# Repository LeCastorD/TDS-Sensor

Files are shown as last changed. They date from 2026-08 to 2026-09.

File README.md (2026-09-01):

<div align="center">
  <h1>TDS Sensor</h1>
  <p><strong>ESP8266 TDS and temperature sensor for Home Assistant</strong></p>
  <p>
    <a href="#build-with-platformio">Build</a> |
    <a href="#wiring">Wiring</a> |
    <a href="#enclosure-and-assembly">Enclosure</a> |
    <a href="#first-setup">First setup</a>
  </p>
</div>

<p align="center">
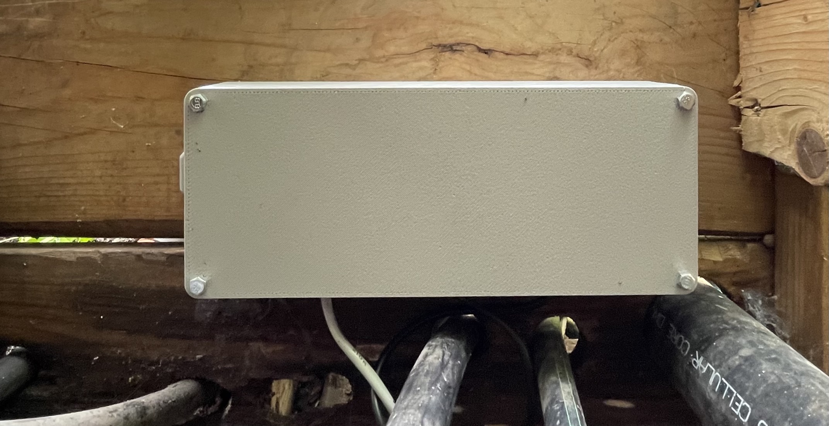
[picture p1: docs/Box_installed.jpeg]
Installed TDS Sensor enclosure
  
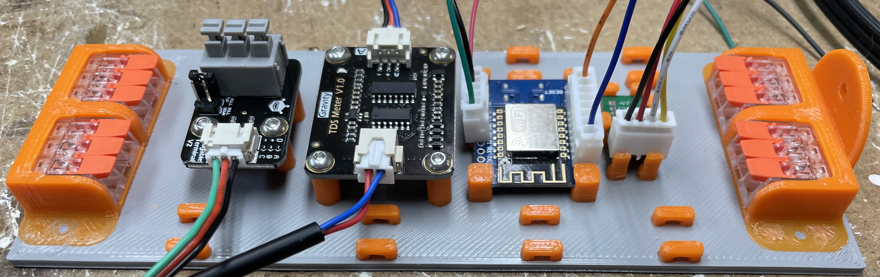
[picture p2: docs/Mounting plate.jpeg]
Populated sensor mounting plate
  
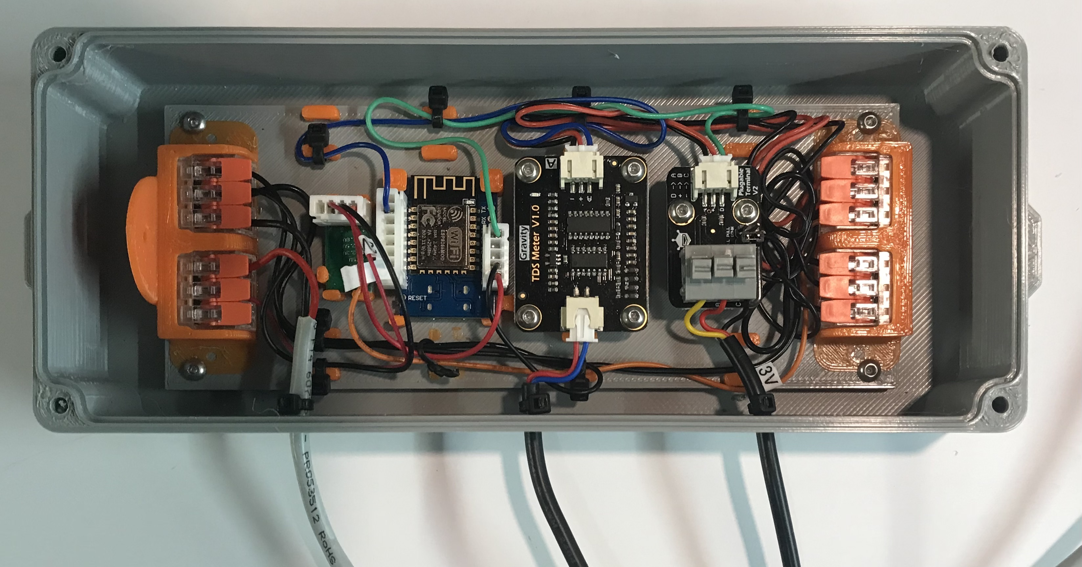
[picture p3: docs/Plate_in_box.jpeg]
Mounting plate installed in the enclosure
  
</p>

<h2 id="table-of-contents">Table of Contents</h2>

<ul>
  <li><a href="#overview">Overview</a></li>
  <li><a href="#features">Features</a></li>
  <li><a href="#hardware">Hardware</a></li>
  <li><a href="#device-naming">Device naming</a></li>
  <li><a href="#component-reference">Component reference</a></li>
  <li><a href="#soldering">Soldering the power and controller connections</a></li>
  <li><a href="#buck-converter-5v-jumper">Buck converter 5 V jumper</a></li>
  <li><a href="#crimping-and-wire-preparation">Crimping connectors and preparing wires</a></li>
  <li><a href="#wiring">Wiring</a></li>
  <li><a href="#bill-of-materials">Bill of materials</a></li>
  <li><a href="#enclosure-and-assembly">Enclosure and assembly</a></li>
  <li><a href="#build-with-platformio">Build with PlatformIO</a></li>
  <li><a href="#upload-firmware">Upload firmware</a></li>
  <li><a href="#ota-upgrade">OTA upgrade and LittleFS data</a></li>
  <li><a href="#initial-wi-fi-configuration">Initial Wi-Fi configuration</a></li>
  <li><a href="#default-web-ui-login">Default Web UI login</a></li>
  <li><a href="#first-setup">First setup</a></li>
  <li><a href="#web-ui-reference">Web UI reference</a></li>
  <li><a href="#home-assistant-interface">Home Assistant interface</a></li>
  <li><a href="#security">Security</a></li>
  <li><a href="#repository-layout">Repository layout</a></li>
  <li><a href="#license">License</a></li>
  <li><a href="#disclaimer">Disclaimer</a></li>
</ul>

<h2 id="overview">Overview</h2>

<p>
  This project measures total dissolved solids (TDS) and water temperature with an ESP8266 controller. It reads a DFRobot SEN0244 analog TDS sensor, applies temperature compensation using a DS18B20 probe, and publishes readings through MQTT for Home Assistant.
</p>

<p>
  <strong>TDS range limitation:</strong> the DFRobot SEN0244 has a specified measurement range of <strong>0 to 1000 ppm</strong>. A calculated value above 1000 ppm is outside the sensor's validated recognition range and should not be treated as an accurate measurement; the sensor cannot reliably distinguish higher concentrations. The firmware may still display values above 1000 ppm because its analog calculation is not hard-clamped, but changing the calibration factor does not extend the physical sensor range. See the <a href="https://wiki.dfrobot.com/sen0244/">DFRobot SEN0244 specifications</a> for the manufacturer's range and accuracy information.
</p>

<p>
  <strong>Wi-Fi limitations:</strong> the Wemos D1 Mini used by this project is based on the ESP8266 and supports 2.4 GHz 802.11 b/g/n Wi-Fi, not 5 GHz Wi-Fi. For reliable onboarding and operation, use a dedicated 2.4 GHz network configured for b/g/n compatibility rather than a 5 GHz-only or 802.11ac-only network. Modern access points can sometimes handle this through backward-compatible mixed modes, but a separate legacy-compatible SSID is recommended when the device has connection problems.
</p>

<p>
  The standard Wemos board is best placed within good Wi-Fi coverage. If there is no nearby repeater or access point, consider a compatible ESP8266 board with an external antenna connector, such as an IPEX/U.FL or SMA connector, and a suitable antenna. An external antenna can improve placement flexibility and coverage, but actual performance depends on the antenna, cable, enclosure, and access point. Verify pin compatibility and physical fit before substituting the controller; see the <a href="https://docs.wemos.cc/en/latest/d1/d1_mini.html">WEMOS D1 mini documentation</a>, the <a href="https://docs.wemos.cc/en/latest/d1/d1_mini_pro.html">WEMOS D1 mini Pro documentation</a>, and the <a href="https://documentation.espressif.com/0a-esp8266ex_datasheet_en.html">Espressif ESP8266EX datasheet</a> for board and radio details.
</p>

<h2 id="features">Features</h2>

<ul>
  <li>TDS measurement in ppm through an analog input</li>
  <li>DS18B20 temperature measurement and temperature compensation</li>
  <li>WiFiManager onboarding</li>
  <li>MQTT state publishing and Home Assistant MQTT discovery</li>
  <li>Browser-based configuration and sensor calibration</li>
  <li>OTA firmware updates</li>
  <li>LittleFS configuration and sensor log storage</li>
  <li>Factory reset input on the controller board</li>
</ul>

<h2 id="hardware">Hardware</h2>

<ul>
  <li>Wemos D1 Mini (ESP8266)</li>
  <li>DFRobot SEN0244 analog TDS sensor</li>
  <li>DFRobot DS18B20 temperature probe</li>
  <li>5 V supply for the controller board</li>
  <li>Optional 12 V supply and 12-24 V to 5 V buck converter</li>
</ul>

<h2 id="device-naming">Device naming</h2>

<p>
  When no custom name is saved, the firmware generates the device name using this format:
  <code>tds-tmp-sensor-XXXXXX</code>
</p>

<ul>
  <li>Prefix: <code>tds-tmp-sensor-</code></li>
  <li>Suffix: six uppercase hexadecimal characters</li>
  <li>Identifier source: the ESP8266 value returned by <code>ESP.getChipId()</code>, masked to 24 bits</li>
</ul>

<p>Example: <code>tds-tmp-sensor-ABC123</code>.</p>

<p>
  The code does not take the last four characters of the Wi-Fi MAC address. The helper function is named <code>applyDefaultIdentityFromMac()</code>, but its current implementation uses <code>ESP.getChipId()</code> to create a six-character suffix.
</p>

<p>
  A custom name can be saved from the network settings page. When set, that name replaces the generated default and is used as the Wi-Fi hostname, the mDNS hostname (<code>http://&lt;device-name&gt;.local</code>), the WiFiManager portal name, and the Home Assistant MQTT discovery device identifier.
</p>

<h2 id="component-reference">Component reference</h2>

<p>The following reference photos identify the main electronic, wiring, power, and assembly tools used by this project.</p>

<table>
  <tr>
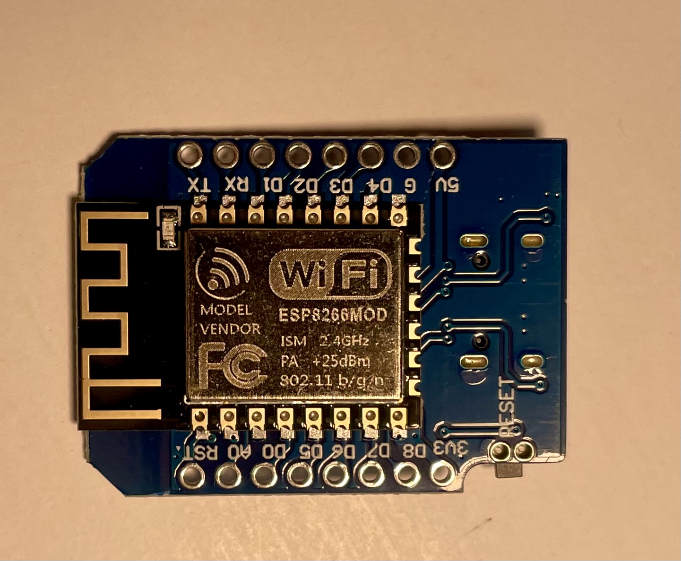
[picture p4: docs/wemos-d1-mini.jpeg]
Wemos D1 Mini ESP8266 board
    <td align="center"><br><em>Wemos D1 Mini</em></td>
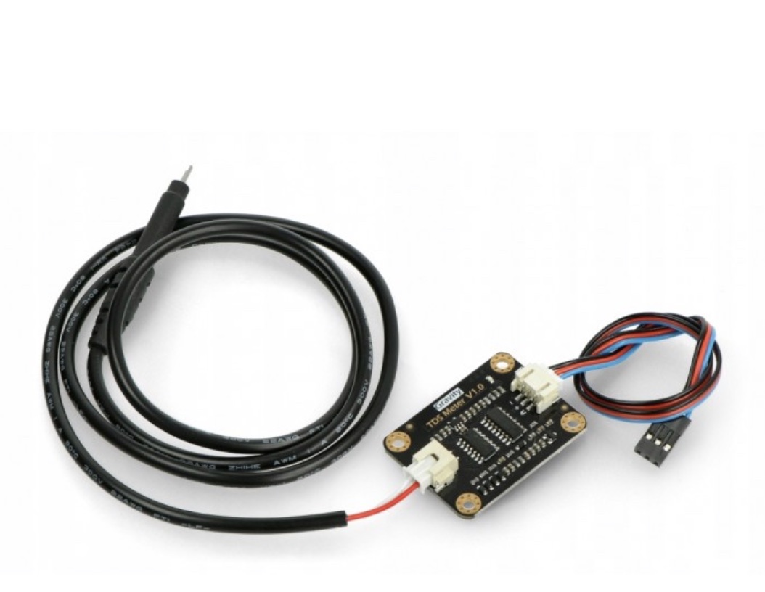
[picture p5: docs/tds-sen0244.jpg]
DFRobot SEN0244 TDS sensor
    <td align="center"><br><em>DFRobot SEN0244 TDS sensor</em></td>
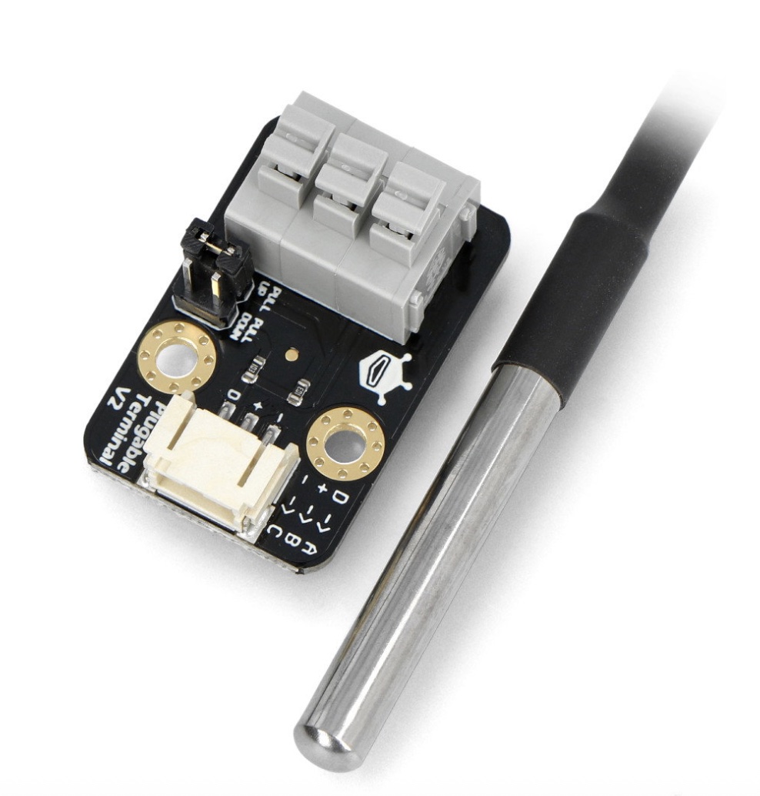
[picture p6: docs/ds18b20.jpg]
DFRobot DS18B20 temperature sensor
    <td align="center"><br><em>DFRobot DS18B20</em></td>
  </tr>
  <tr>
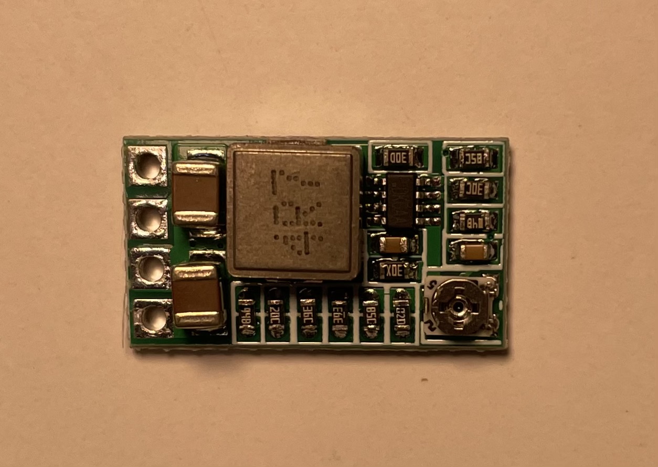
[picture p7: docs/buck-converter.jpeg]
12 to 5 volt buck converter
    <td align="center"><br><em>12-24 V to 5 V buck converter</em></td>
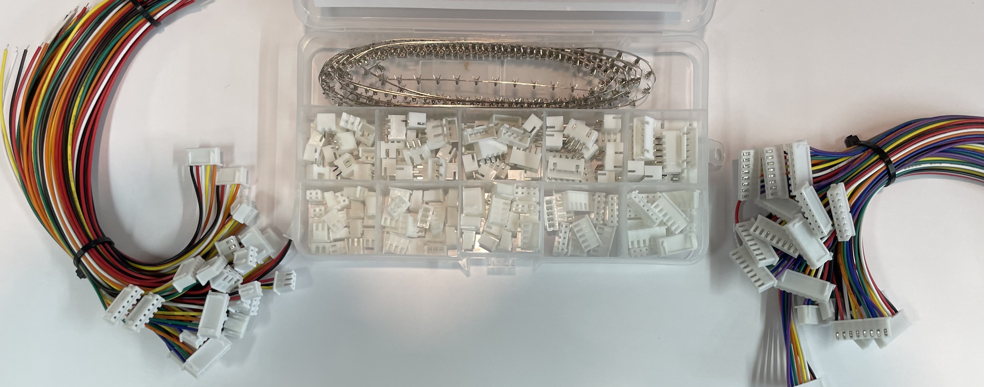
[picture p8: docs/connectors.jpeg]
JST XH connector kit
    <td align="center"><br><em>JST-XH connector kit</em></td>
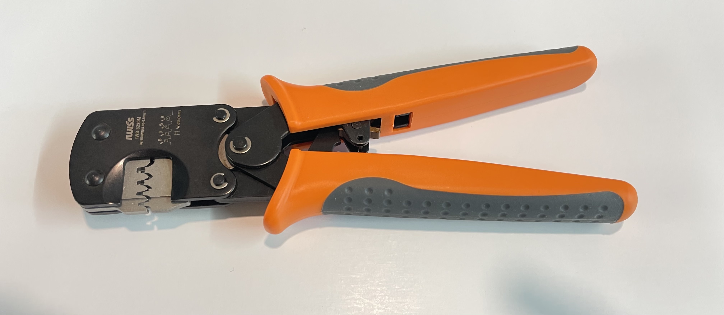
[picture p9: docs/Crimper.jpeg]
JST connector crimping tool
    <td align="center"><br><em>JST connector crimping tool</em></td>
  </tr>
</table>

<h2 id="soldering">Soldering the power and controller connections</h2>

<p>
  Disconnect the 12 V supply and USB cable before soldering. Work from the labels printed on each board and verify every connection with a multimeter before applying power.
</p>

<table>
  <tr>
    <td align="center">Buck converter for the controller power supply<br><em>Buck converter</em></td>
    <td align="center">Wemos D1 Mini controller board<br><em>Wemos D1 Mini</em></td>
  </tr>
</table>

<ol>
  <li>Identify the buck-converter input and output pads. Connect the 12 V supply to <code>IN+</code> and <code>IN-</code>, observing polarity.</li>
  <li>Connect the regulated output to the controller power wiring: <code>OUT+</code> to the Wemos <code>5V</code> pin and <code>OUT-</code> to <code>GND</code>.</li>
  <li>Before connecting the Wemos, power the buck converter from the supply and adjust or verify its output at approximately 5.0 V DC.</li>
  <li>Solder short, clearly identified leads or connector wires to the Wemos pins required by the installation: <code>5V</code>, <code>3V3</code>, <code>GND</code>, <code>A0</code>, <code>D2</code> / <code>GPIO4</code>, and the optional <code>D5</code> / <code>GPIO14</code> factory-reset input. The <code>3V3</code> connection powers the SEN0244 and DS18B20.</li>
  <li>Use heat-shrink tubing on exposed solder joints and add strain relief so the connector cannot pull directly on a pad.</li>
  <li>Check continuity, polarity, and the absence of shorts between <code>5V</code> and <code>GND</code> before connecting the Wemos and sensors.</li>
</ol>

<p><strong>Important:</strong> never connect the 12 V supply directly to the Wemos <code>5V</code> pin, and never connect the buck converter's 5 V output directly to a sensor power input. The buck converter feeds only the Wemos <code>5V</code> pin; the Wemos supplies the SEN0244 and DS18B20 from its <code>3V3</code> and <code>GND</code> pins.</p>

<h3 id="buck-converter-5v-jumper">Set the buck converter to 5 V</h3>

<p>
  This buck-converter board uses solder-selectable output pads on its back. The Wemos requires a regulated 5 V input, while the SEN0244 and DS18B20 are powered from the Wemos <code>3V3</code> rail. Bridge only the two pads marked <code>5V</code> before connecting the controller.
</p>

<p align="center">
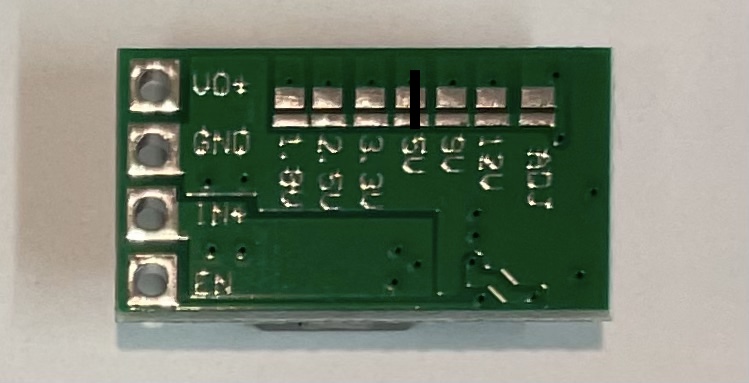
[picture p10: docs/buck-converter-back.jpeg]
Back of the buck converter showing the solder-selectable voltage pads
  
</p>

<ol>
  <li>Disconnect the 12 V supply and USB cable from the project.</li>
  <li>Turn the converter over and locate the output-selection row and the <code>5V</code> marking shown in the reference image.</li>
  <li>Use a small amount of flux and solder to bridge the two pads for the <code>5V</code> selection.</li>
  <li>Check that the solder bridge does not touch the neighboring voltage-selection pads. Remove any unintended bridge before powering the board.</li>
  <li>Power the converter from the 12 V supply and measure between <code>VOUT+</code> and <code>GND</code>. Confirm approximately 5.0 V DC before connecting the Wemos.</li>
</ol>

<p><strong>Important:</strong> the jumper selects the converter output voltage; it does not replace the voltage measurement. Do not connect the Wemos until the measured output is correct.</p>

<h2 id="crimping-and-wire-preparation">Crimping connectors and preparing wires</h2>

<p>
  This section refers to the JST-XH/XH2.54 connectors listed in the BOM. Use the correct contact size and housing for the prewired connector kit; do not force a terminal into a mismatched housing.
</p>

<p align="center">
  JST-XH connector kit and prewired wires
  JST connector crimping tool
</p>

<ol>
  <li>Install the buck converter, Wemos, terminal blocks, and sensor electronics in their final positions on the mounting plate before measuring wires.</li>
  <li>Route each wire along its final path and measure from connector to connector. Keep runs as short as practical, but leave enough slack to unplug a connector and remove the plate without stressing the wires.</li>
  <li>Cut and label one wire at a time. Keep power, ground, analog signal, and one-wire data conductors identifiable at both ends.</li>
  <li>Plan the sensor power branches from the Wemos: route <code>3V3</code> to the SEN0244 supply and the DS18B20 power lead, and route <code>GND</code> back to the Wemos common ground. Do not route the buck converter's <code>5V</code> output to either sensor.</li>
  <li>Strip only the length required by the contact manufacturer, typically about 2-3 mm for small JST-XH contacts. Do not nick or remove conductor strands.</li>
  <li>Place the stripped conductor in the contact so the conductor wings crimp onto bare copper and the insulation wings support the cable jacket.</li>
  <li>Crimp with the correct die position, then inspect the joint. The conductor should be held firmly without cutting through the wire or leaving loose strands.</li>
  <li>Perform a gentle pull test on every crimp, then insert the contact into the housing until the locking tang clicks. Confirm the pin order and connector keying before mating it.</li>
  <li>Use a multimeter to verify continuity end-to-end and confirm that adjacent pins are not shorted.</li>
</ol>

<table>
  <thead>
    <tr>
      <th>Connection</th>
      <th>Routing guidance</th>
    </tr>
  </thead>
  <tbody>
    <tr>
      <td>Buck <code>OUT+</code> to Wemos <code>5V</code></td>
      <td>Use the shortest safe power run and verify 5 V before connection.</td>
    </tr>
    <tr>
      <td>Buck <code>OUT-</code> to Wemos <code>GND</code></td>
      <td>Use a short ground run; the Wemos <code>GND</code> is the common return for both sensors.</td>
    </tr>
    <tr>
      <td>Wemos <code>3V3</code> to SEN0244 and DS18B20 power</td>
      <td>Branch the Wemos 3.3 V rail to both sensor supply inputs. Never use buck <code>OUT+</code> for sensor power.</td>
    </tr>
    <tr>
      <td>Wemos <code>GND</code> to SEN0244 and DS18B20 ground</td>
      <td>Keep the sensor returns common with the Wemos and buck-converter ground.</td>
    </tr>
    <tr>
      <td>Wemos <code>A0</code> to SEN0244 analog output</td>
      <td>Keep the analog signal wire short and separated from unnecessary power loops.</td>
    </tr>
    <tr>
      <td>Wemos <code>D2</code> / <code>GPIO4</code> to DS18B20 data</td>
      <td>Route directly to the temperature connector and avoid excess coiled wire.</td>
    </tr>
  </tbody>
</table>

<p>
  The goal is a compact harness with no loose loops, while retaining enough service slack for inspection, connector removal, and enclosure maintenance. See <a href="docs/BOM.md#component-images">docs/BOM.md</a> for the component images and parts list.
</p>

<h2 id="wiring">Wiring</h2>

<p align="center">
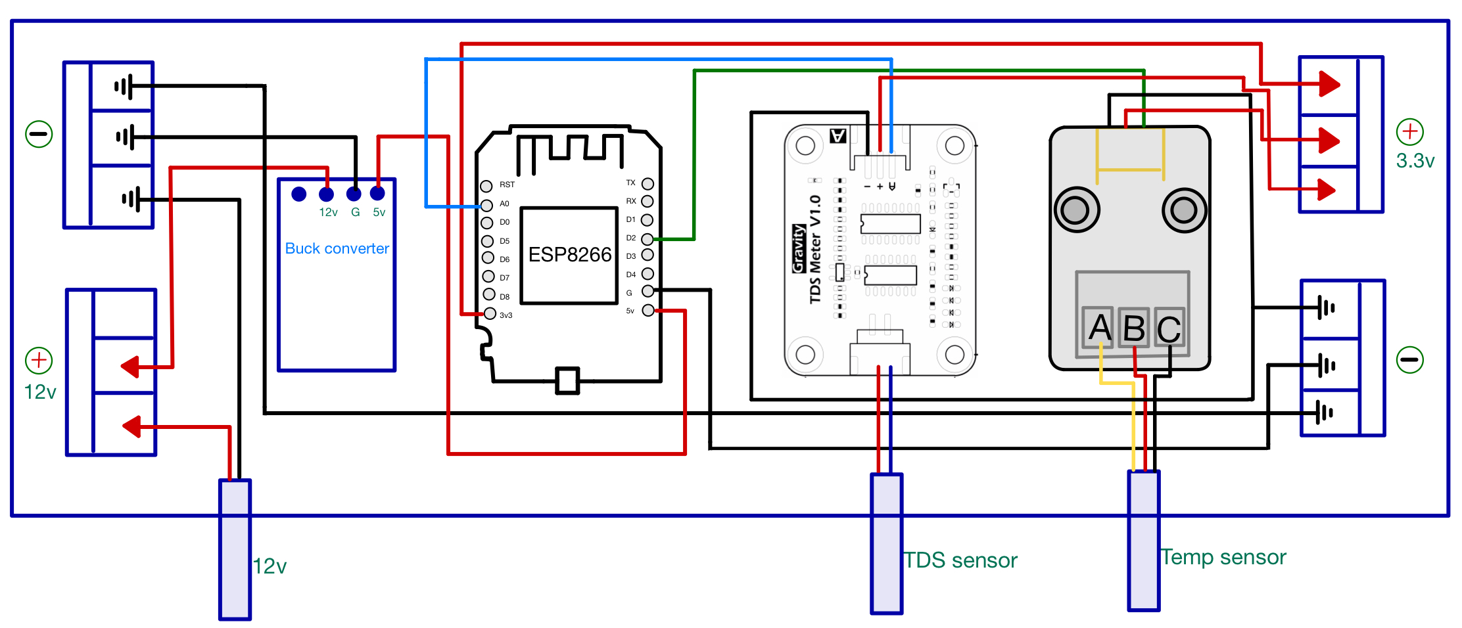
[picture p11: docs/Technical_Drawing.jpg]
TDSTMPSensor technical wiring drawing showing the buck converter, Wemos, TDS sensor, and temperature sensor connections
  <br>
  <em>Technical wiring drawing: 12 V supply to the buck converter, buck converter 5 V output to the Wemos, and Wemos 3.3 V power to both sensors.</em>
</p>

<table>
  <thead>
    <tr>
      <th>Controller pin</th>
      <th>Connection</th>
    </tr>
  </thead>
  <tbody>
    <tr>
      <td><code>A0</code></td>
      <td>SEN0244 analog TDS output</td>
    </tr>
    <tr>
      <td><code>D2</code> / <code>GPIO4</code></td>
      <td>DS18B20 one-wire data</td>
    </tr>
    <tr>
      <td><code>D5</code> / <code>GPIO14</code></td>
      <td>Factory reset input, jumper to GND at boot</td>
    </tr>
    <tr>
      <td><code>5V</code></td>
      <td>Buck converter <code>OUT+</code> to Wemos power input only</td>
    </tr>
    <tr>
      <td><code>3V3</code></td>
      <td>Wemos 3.3 V output to SEN0244 and DS18B20 power inputs</td>
    </tr>
    <tr>
      <td><code>GND</code></td>
      <td>Common ground for buck converter, Wemos, SEN0244, and DS18B20</td>
    </tr>
  </tbody>
</table>

<p><strong>Power path:</strong> 12 V supply &rarr; buck converter &rarr; Wemos <code>5V</code>; Wemos <code>3V3</code> &rarr; SEN0244 and DS18B20. The sensor power inputs must not be connected directly to the 5 V buck output.</p>

<p>See <a href="docs/hardware-pinout.md">docs/hardware-pinout.md</a> for board assumptions and electrical notes.</p>

<h2 id="bill-of-materials">Bill of materials</h2>

<p>See the complete parts list, assembly hardware, 3D-printing notes, and enclosure credits in <a href="docs/BOM.md">docs/BOM.md</a>.</p>

<h2 id="enclosure-and-assembly">Enclosure and assembly</h2>

<p>The repository includes the current 3MF files for the enclosure and sensor plate:</p>

<ul>
  <li><a href="Enclosure%20and%20mount/Box.3mf">Box.3mf</a></li>
  <li><a href="Enclosure%20and%20mount/Sensor%20Plate.3mf">Sensor Plate.3mf</a></li>
</ul>

<table>
  <tr>
    <td align="center">Populated mounting plate<br><em>Populated mounting plate</em></td>
    <td align="center">Plate installed in the enclosure<br><em>Plate installed in the enclosure</em></td>
  </tr>
  <tr>
    <td align="center" colspan="2">Installed enclosure<br><em>Installed enclosure</em></td>
  </tr>
</table>

<p>
  The parts list identifies the board holders, capacitor holder, connector holder, cable-tie holder, and standoffs used by the assembly. Confirm dimensions and clearances against your exact components before printing.
</p>

<h2 id="build-with-platformio">Build with PlatformIO</h2>

<h3>Requirements</h3>

<ul>
  <li>VS Code with the PlatformIO extension, or PlatformIO CLI</li>
  <li>A Wemos D1 Mini connected by USB</li>
  <li>The dependencies listed in <a href="platformio.ini">platformio.ini</a></li>
</ul>

<p>From the project directory:</p>

<pre><code>pio run</code></pre>

<p>
  The build target is <code>WEMOS_D1_Mini</code>. The pre-build script automatically increments the local build number and updates <code>include/fw_version_auto.h</code>.
</p>

<h2 id="upload-firmware">Upload firmware</h2>

<p>Replace <code>&lt;PORT&gt;</code> with the serial port assigned to your board:</p>

<pre><code>pio run -t upload --upload-port &lt;PORT&gt;
pio run -t uploadfs --upload-port &lt;PORT&gt;</code></pre>

<p>
  The first command uploads the firmware. The second uploads the LittleFS web interface and filesystem data. For the exported release images, see <a href="artifacts/reflash/FLASHING.md">artifacts/reflash/FLASHING.md</a>.
</p>

<h2 id="ota-upgrade">OTA upgrade and LittleFS data</h2>

<p>
  <strong>Important:</strong> the firmware and LittleFS are separate flash areas. A firmware-only OTA update normally preserves the settings, but uploading a new LittleFS image replaces the filesystem contents. This removes <code>/config.json</code> and <code>/sensor_readings.csv</code>, so all runtime settings stored in <code>config.json</code> are lost unless they are restored from a backup.
</p>

<h3>Firmware-only OTA update</h3>

<ol>
  <li>Log in to the device Web UI at <code>http://&lt;device-ip&gt;/login</code> if authentication is enabled.</li>
  <li>From the home page select <strong>Firmware Upgrade</strong>. This opens the OTA page at <code>/update</code>.</li>
  <li>Upload the firmware <code>.bin</code> file only, then wait for the controller to restart. Do not upload a LittleFS image unless the web interface or filesystem contents must also be updated.</li>
  <li>After the restart, open <strong>Settings &gt; MQTT Settings</strong> and confirm that the MQTT connection is restored.</li>
</ol>

<h3>Upgrade that includes LittleFS</h3>

<p>
  Use this procedure whenever you upload a LittleFS image, including <code>pio run -t uploadfs</code> or an exported <code>*-littlefs.bin</code> image. The filesystem image contains the web interface, but it also replaces the persistent configuration and sensor log. The saved Wi-Fi credentials managed by WiFiManager may remain outside LittleFS, but the device hostname, MQTT settings, OTA credentials, time zone, sensor calibration, intervals, and other values stored in <code>config.json</code> will not.
</p>

<ol>
  <li>
    <strong>Back up before updating:</strong> open <strong>Settings &gt; Backup &amp; Restore</strong> at <code>/settings/backup_restore</code>. Select <strong>Download config.json</strong> and keep the downloaded file outside the project. Select <strong>Download sensor_readings.csv</strong> as well if the measurement history is needed.
  </li>
  <li>
    <strong>Perform the update:</strong> upload the new firmware and LittleFS images using the method described in <a href="#upload-firmware">Upload firmware</a> or <a href="artifacts/reflash/FLASHING.md">the release flashing instructions</a>. Expect the LittleFS upload to erase the previous configuration and sensor log.
  </li>
  <li>
    <strong>Reconnect after the update:</strong> use the device IP address if the previous hostname no longer works. Because the stored OTA credentials were erased, the firmware defaults are used until the backup is restored: username <code>admin</code>, password <code>adminpass</code>. Open <code>http://&lt;device-ip&gt;/login</code>.
  </li>
  <li>
    <strong>Restore the configuration:</strong> open <strong>Settings &gt; Backup &amp; Restore</strong>, choose the saved <code>config.json</code> file, and select <strong>Restore config.json</strong>. Reboot the controller after the restore so the device name, MQTT topic paths, and all loaded settings are applied consistently.
  </li>
  <li>
    <strong>Verify the installation:</strong> check <strong>Settings &gt; Networking</strong>, <strong>Settings &gt; MQTT Settings</strong>, <strong>Settings &gt; OTA Settings</strong>, <strong>Settings &gt; Time Synchronization</strong>, and <strong>Settings &gt; Sensor Settings</strong>. Confirm the device reports <strong>MQTT Status CONNECTED</strong>, then check Home Assistant discovery.
  </li>
</ol>

<p>
  If the backup is not restored, the device returns to its default identity and settings. Home Assistant uses the device name when it creates discovery identifiers and entity unique IDs, so it may create a new device while the previous entities remain orphaned. In that case the Home Assistant device and dashboard must be reconfigured. Restoring <code>config.json</code> preserves the previous identity and avoids this unnecessary reconfiguration.
</p>

<h2 id="initial-wi-fi-configuration">Initial Wi-Fi configuration</h2>

<p>
  This project uses <a href="https://github.com/tzapu/WiFiManager">WiFiManager</a> to configure the wireless network without hard-coding an SSID or password in the firmware. The official WiFiManager project provides the library documentation, examples, and configuration details.
</p>

<ol>
  <li>Power the device with no saved Wi-Fi credentials, or clear its previous network configuration.</li>
  <li>Wait for the controller to start its WiFiManager configuration access point. The access-point name is the current device name, for example <code>tds-tmp-sensor-ABC123</code>.</li>
  <li>Connect a phone or computer to that temporary access point. A captive portal should open automatically; if it does not, open the configuration page shown by WiFiManager.</li>
  <li>Select the local Wi-Fi network, enter its password, and save the configuration.</li>
  <li>After the controller restarts or reconnects, return to the normal Wi-Fi network and open the device using its assigned IP address or mDNS name, such as <code>http://tds-tmp-sensor-ABC123.local</code>.</li>
</ol>

<p>
  The firmware calls <code>wm.autoConnect(deviceName)</code> during startup. Once credentials are saved, it attempts to reconnect automatically on later boots. For WiFiManager-specific behavior and troubleshooting, see the <a href="https://github.com/tzapu/WiFiManager">official WiFiManager documentation</a>.
</p>

<h2 id="default-web-ui-login">Default Web UI login</h2>

<p>
  The initial Web UI and OTA credentials are case-sensitive:
</p>

<table>
  <tr><th>Username</th><td><code>admin</code></td></tr>
  <tr><th>Password</th><td><code>adminpass</code></td></tr>
</table>

<p>
  Open <code>http://&lt;device-ip&gt;/login</code> when Web UI login is required. These are the credentials currently defined by the firmware; <code>Admin</code> and <code>Adminpass</code> with uppercase initials will not work unless the firmware defaults are changed. After signing in, change them at <strong>Settings &gt; OTA Settings</strong>, then select <strong>Save OTA Settings</strong>. The OTA credentials are also used to access the Web UI.
</p>

<h2 id="first-setup">First setup</h2>

<ol>
  <li>
    <strong>Upload the firmware and web interface:</strong> from the PlatformIO project, upload the firmware and then upload the LittleFS image. The web pages used below are stored in <code>data/web/</code> and must be present on the controller.
  </li>
  <li>
    <strong>Start the controller:</strong> power-cycle the device and wait for it to finish booting. If Web UI login is enabled, open <code>http://&lt;device-ip&gt;/login</code> and sign in with the OTA user and password.
  </li>
  <li>
    <strong>Configure Wi-Fi when required:</strong> if no Wi-Fi credentials are saved, join the WiFiManager access point first and follow <a href="#initial-wi-fi-configuration">Initial Wi-Fi configuration</a>. After the device joins the network, open <code>http://&lt;device-ip&gt;/</code> or <code>http://&lt;device-name&gt;.local/</code>.
  </li>
  <li>
    <strong>Configure the device settings:</strong> from the home page select <strong>Settings</strong>. Use the following paths and save each page before continuing:
    <ul>
      <li><strong>Settings &gt; Networking:</strong> set the <strong>Hostname</strong> and choose <strong>Automatic (DHCP)</strong> or enter the <strong>Static IP</strong>, <strong>Gateway</strong>, <strong>Netmask</strong>, and <strong>DNS</strong>. Select <strong>Save Networking</strong>. Network mode or IP changes may require a reboot.</li>
      <li><strong>Settings &gt; Sensor Settings:</strong> review the <strong>TDS calibration factor</strong>, <strong>TDS offset (ppm)</strong>, <strong>Temperature offset (C)</strong>, <strong>Temperature compensation cutoff (V)</strong>, <strong>Sample interval (s)</strong>, and <strong>Publish interval (s)</strong>. Select <strong>Save Sensor Settings</strong>.</li>
      <li><strong>Settings &gt; Time Synchronization:</strong> enter the POSIX <strong>Time zone</strong> string, for example <code>EST5EDT,M3.2.0/2,M11.1.0/2</code>, then select <strong>Apply Time Zone</strong>.</li>
      <li><strong>Settings &gt; MQTT Settings:</strong> enter <strong>Broker IP / Host</strong>, <strong>Broker port</strong> (normally <code>1883</code>), <strong>Client ID</strong>, <strong>MQTT user</strong>, and <strong>MQTT pass</strong>. Select <strong>Save MQTT Settings</strong>. The page should then report <strong>MQTT Status CONNECTED</strong>.</li>
      <li><strong>Settings &gt; OTA Settings:</strong> set the <strong>OTA user</strong> and <strong>OTA pass</strong>. Enable <strong>Require Web UI login</strong> when the interface should require authentication, then select <strong>Save OTA Settings</strong>. The same OTA credentials are used for Web UI login.</li>
    </ul>
    <p>
      Direct page paths are <code>/settings/network</code>, <code>/settings/sensors</code>, <code>/settings/time</code>, <code>/settings/mqtt</code>, and <code>/settings/ota</code>. The corresponding save actions are performed by the page buttons; do not browse directly to the save paths.
    </p>
  </li>
  <li>
    <strong>Verify MQTT and Home Assistant:</strong> return to <code>http://&lt;device-ip&gt;/</code>, open <strong>Settings &gt; MQTT Settings</strong>, and confirm <strong>MQTT Status CONNECTED</strong>. Then check Home Assistant for the automatically discovered device and its entities.
  </li>
  <li>
    <strong>Calibrate the sensor:</strong> go to <strong>Settings &gt; Sensor Settings</strong>, set the calibration factor and offset as required by the reference solution, select <strong>Save Sensor Settings</strong>, and confirm the reading in <strong>Live Measurements</strong> or Home Assistant.
  </li>
</ol>

<p>The MQTT topic contract is documented in <a href="docs/mqtt-contract-v1.md">docs/mqtt-contract-v1.md</a>.</p>

<h2 id="web-ui-reference">Web UI reference</h2>

<p>
  The following screenshots show the web interface included in the firmware. The paths in the captions are the corresponding device URLs. The displayed measurements, addresses, and configuration values come from one installation and are examples only; replace or redact installation-specific values before publishing if required.
</p>

<h3>Home page and measurements</h3>

<table>
  <tr>
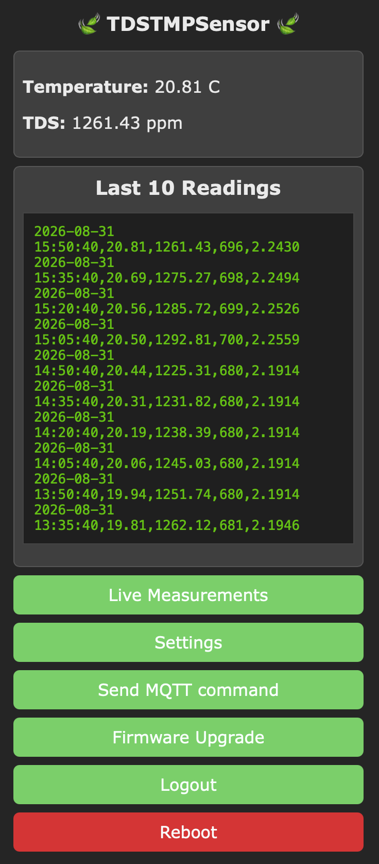
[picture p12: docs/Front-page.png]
TDSTMPSensor web interface home page
    <td align="center"><br><em>Home page: <code>/</code></em></td>
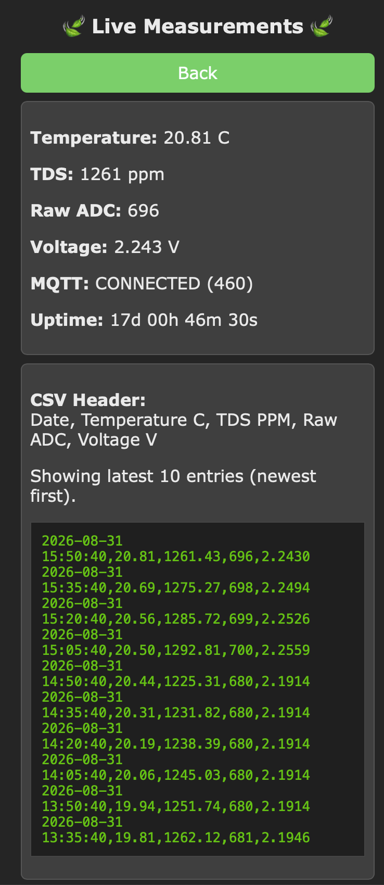
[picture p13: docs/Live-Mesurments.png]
TDSTMPSensor live measurements page
    <td align="center"><br><em>Live Measurements: <code>/measurements</code></em></td>
  </tr>
</table>

<h3>Settings and configuration</h3>

<table>
  <tr>
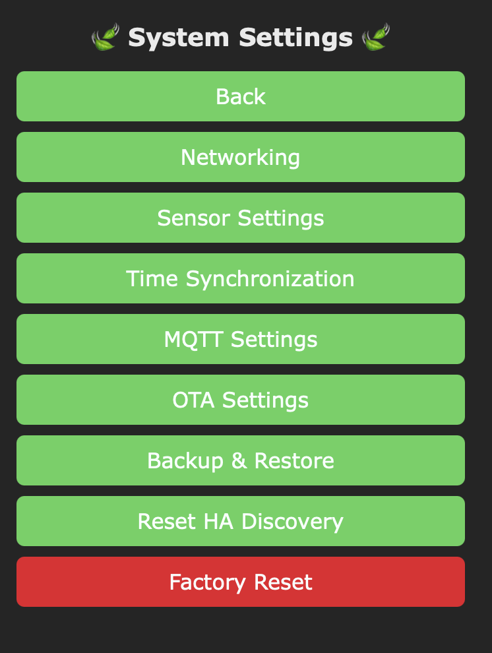
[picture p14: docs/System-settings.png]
TDSTMPSensor system settings menu
    <td align="center"><br><em>System Settings: <code>/settings</code></em></td>
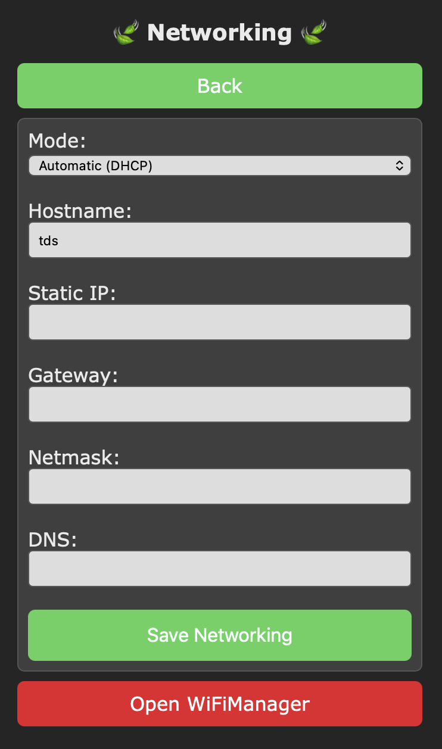
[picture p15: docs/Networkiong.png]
TDSTMPSensor networking settings page
    <td align="center"><br><em>Networking: <code>/settings/network</code></em></td>
  </tr>
  <tr>
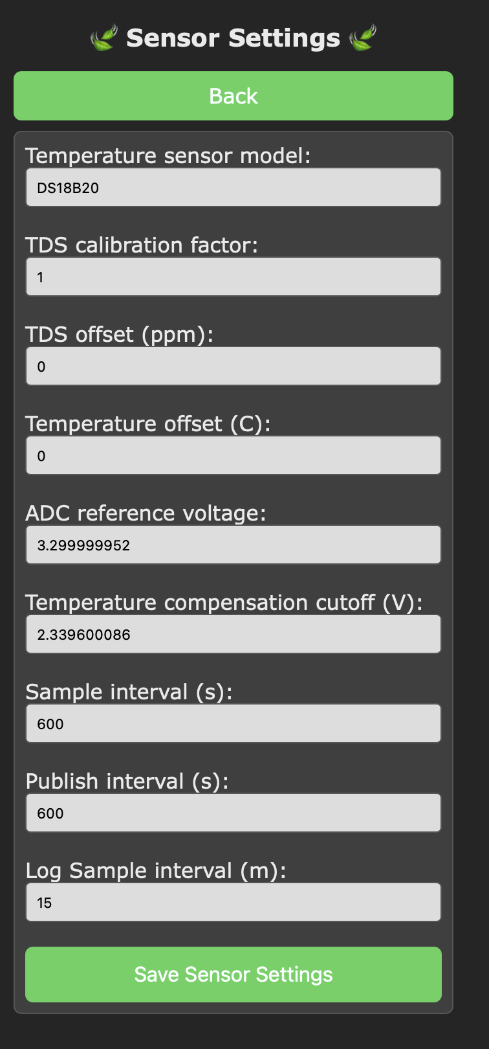
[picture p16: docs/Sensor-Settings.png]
TDSTMPSensor sensor settings page
    <td align="center"><br><em>Sensor Settings: <code>/settings/sensors</code></em></td>
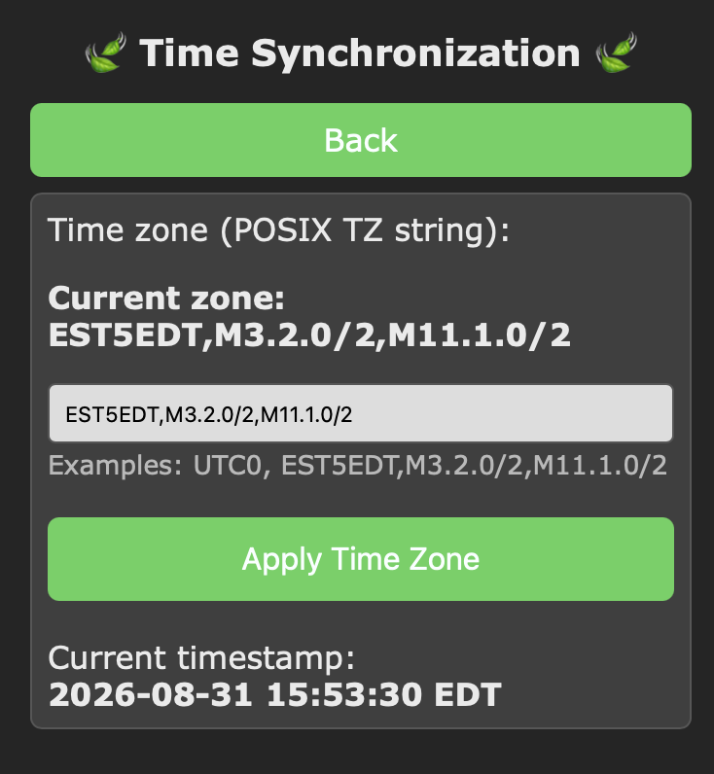
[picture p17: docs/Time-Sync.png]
TDSTMPSensor time synchronization page
    <td align="center"><br><em>Time Synchronization: <code>/settings/time</code></em></td>
  </tr>
  <tr>
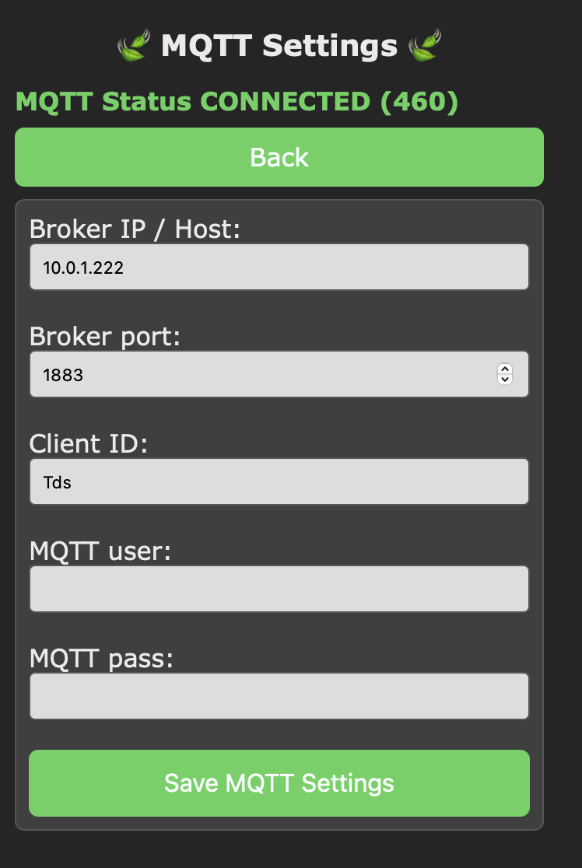
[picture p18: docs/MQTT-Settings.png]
TDSTMPSensor MQTT settings page
    <td align="center"><br><em>MQTT Settings: <code>/settings/mqtt</code></em></td>
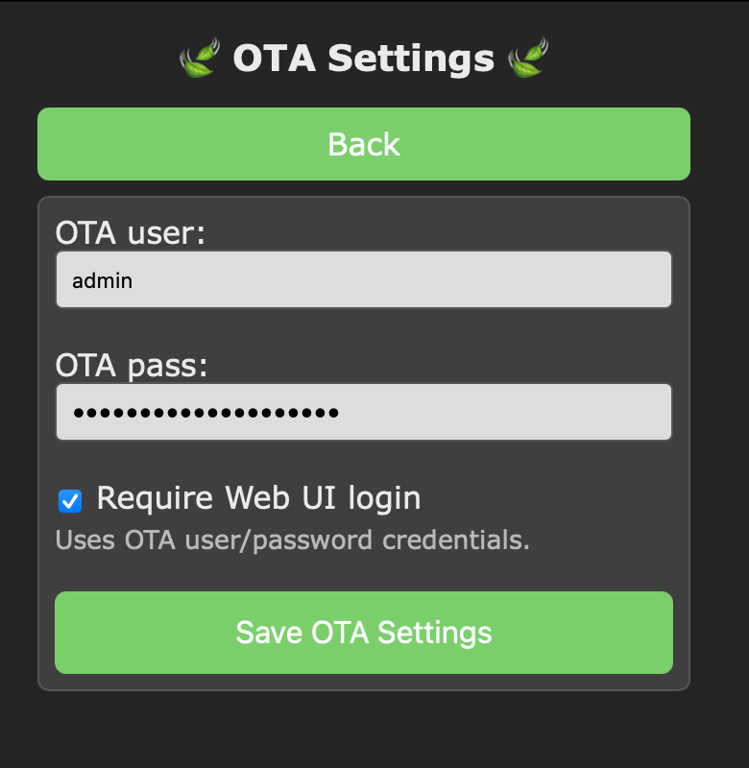
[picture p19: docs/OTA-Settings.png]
TDSTMPSensor OTA settings page
    <td align="center"><br><em>OTA Settings: <code>/settings/ota</code></em></td>
  </tr>
</table>

<h3>Backup, commands, and reset</h3>

<table>
  <tr>
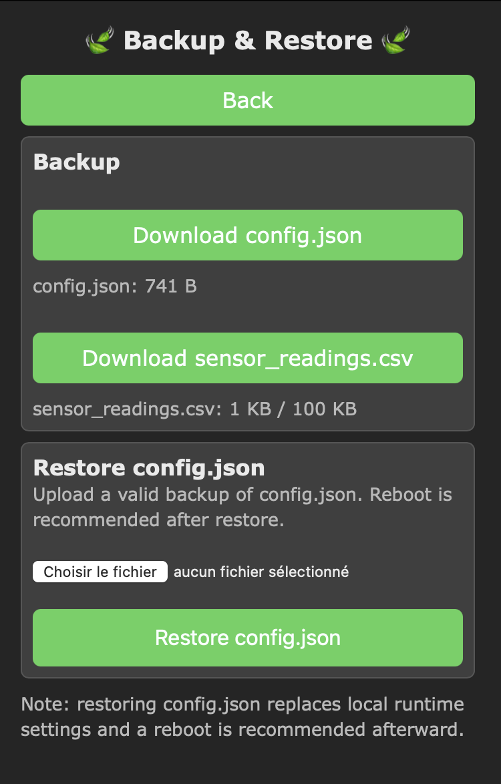
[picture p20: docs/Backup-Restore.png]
TDSTMPSensor backup and restore page
    <td align="center"><br><em>Backup &amp; Restore: <code>/settings/backup_restore</code></em></td>
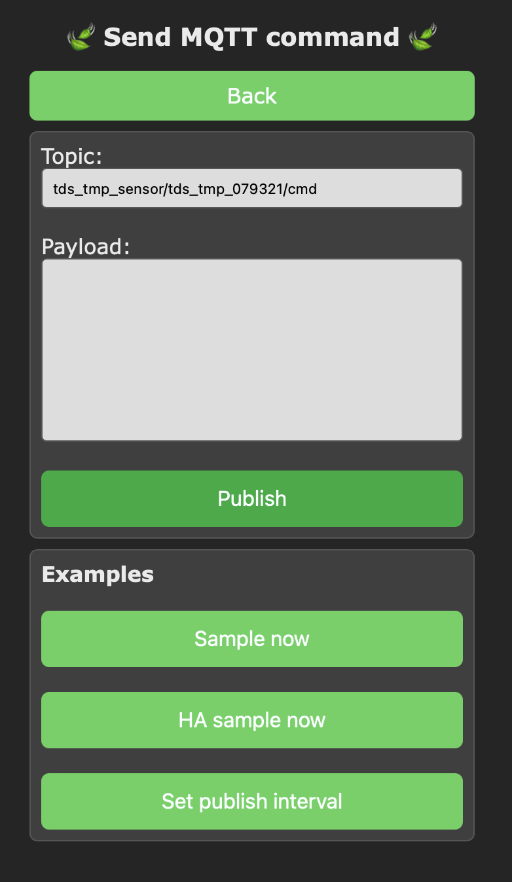
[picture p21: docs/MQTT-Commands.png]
TDSTMPSensor MQTT command page
    <td align="center"><br><em>Send MQTT command: <code>/mqtt_send</code></em></td>
  </tr>
  <tr>
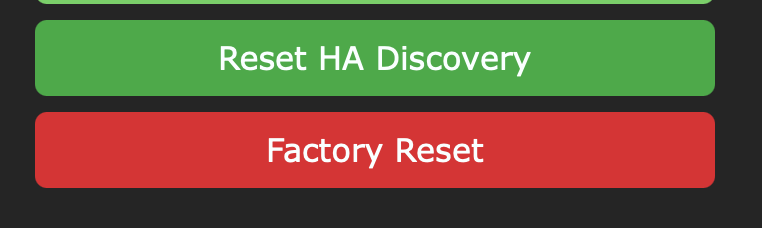
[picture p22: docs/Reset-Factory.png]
TDSTMPSensor Home Assistant discovery reset and factory reset controls
    <td align="center" colspan="2"><br><em>Reset controls at the bottom of <code>/settings</code></em></td>
  </tr>
</table>

<h3>Reset controls</h3>

<p>
  <strong>Reset HA Discovery:</strong> selecting <strong>Settings &gt; Reset HA Discovery</strong> opens <code>/ha_discovery_reset</code> and asks the firmware to republish the current Home Assistant MQTT discovery messages. This is useful when Home Assistant has lost the device entities or needs the current entity definitions published again. It does not erase the device configuration, Wi-Fi credentials, sensor log, or existing Home Assistant entities.
</p>

<p>
  <strong>Factory Reset:</strong> selecting <strong>Settings &gt; Factory Reset</strong> opens the confirmation page at <code>/factory</code>. Confirming the action at <code>/factory_confirm</code> clears the saved Wi-Fi credentials through WiFiManager, deletes <code>/config.json</code>, and reboots the controller. The web interface files and <code>/sensor_readings.csv</code> are not deleted by this handler, but the device returns to its default runtime settings and generated device identity. Wi-Fi setup and all device settings must be completed again after the reboot. The same factory reset can also be triggered by holding the <code>D5</code> / <code>GPIO14</code> reset input low for at least three seconds during boot.
</p>

<h2 id="home-assistant-interface">Home Assistant interface</h2>

<p>
  After MQTT discovery is enabled, the device appears in Home Assistant with its sensor readings and calibration controls. The device page exposes TDS, water temperature, raw ADC, voltage, calibration factor, offsets, sample interval, publish interval, and a manual sample control.
</p>

<table>
  <tr>
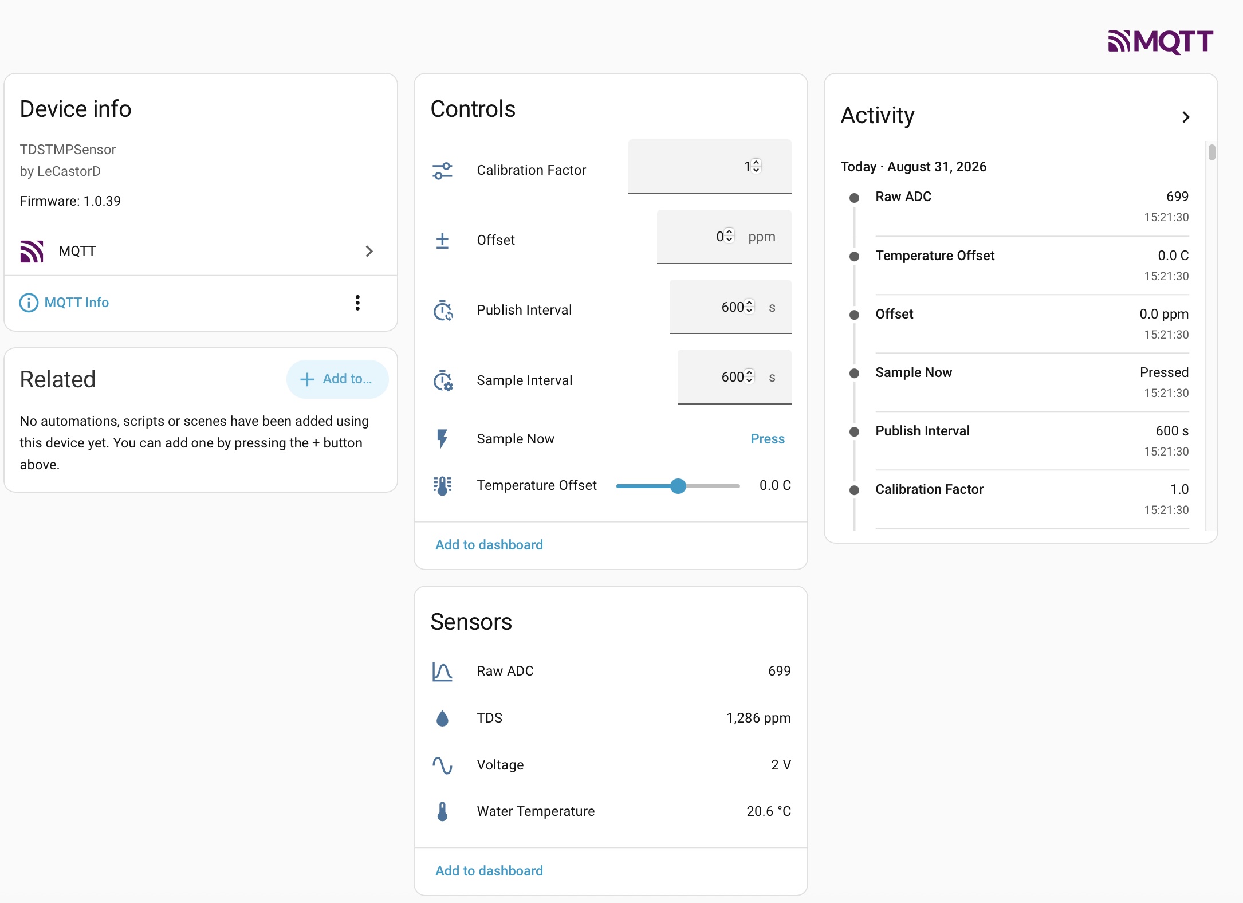
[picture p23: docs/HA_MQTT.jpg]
Home Assistant MQTT device page for the TDS sensor
    <td align="center"><br><em>MQTT-discovered TDS sensor device page</em></td>
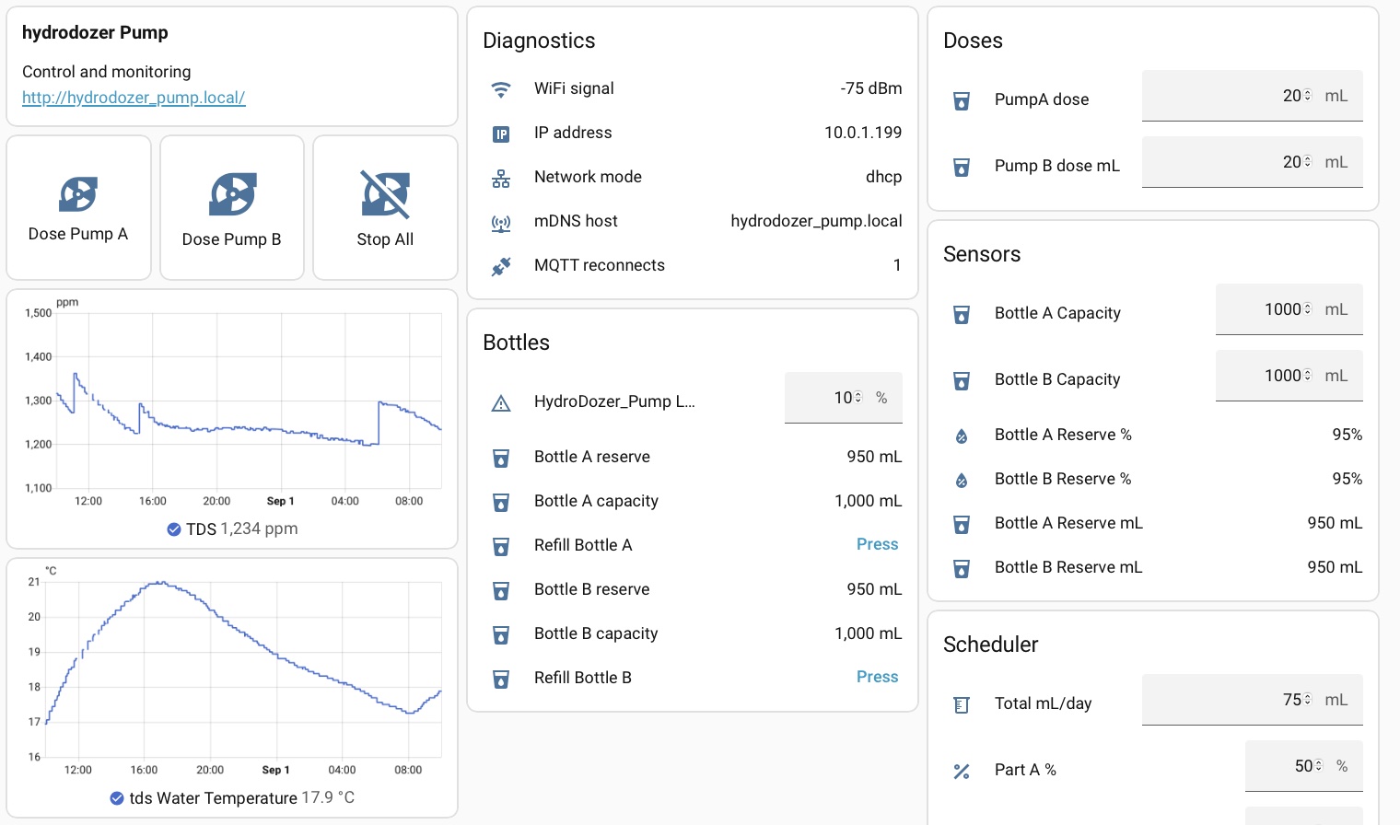
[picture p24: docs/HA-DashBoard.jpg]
Home Assistant dashboard with TDS and water temperature history
    <td align="center"><br><em>Dashboard view with TDS and water temperature history</em></td>
  </tr>
</table>

<p>
  The dashboard screenshot is from a broader HydroDozer installation and includes unrelated pump controls and local network details. Those controls are not provided by this TDS Sensor firmware; use the image as an example of adding the TDS and temperature entities to a Home Assistant dashboard.
</p>

<h2 id="security">Security</h2>

<p>
  The firmware includes example default MQTT and OTA credentials for initial development. Change them before deploying the device on a network that is not fully trusted. Do not commit a device-specific configuration file, Wi-Fi password, MQTT password, or OTA password to this repository.
</p>

<h2 id="repository-layout">Repository layout</h2>

<pre><code>src/TDSTMPSensor/       Firmware source
data/web/               Web interface files stored in LittleFS
docs/                   Wiring, BOM, photos, and MQTT documentation
Enclosure and mount/    3D-printable 3MF files
artifacts/reflash/      Exported firmware and LittleFS images
platformio.ini          PlatformIO project configuration</code></pre>

<h2 id="license">License</h2>

<p>This project is licensed under the MIT License. See <a href="LICENSE">LICENSE</a> for the full text.</p>

<h2 id="disclaimer">Disclaimer</h2>

<p>Parts of this project were developed with the help of AI tools. The project should be reviewed, tested, and validated before use.</p>

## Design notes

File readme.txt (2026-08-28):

TDSTMPSensor

This project reuses the HydroDozerPump infrastructure:
- PlatformIO / ESP8266 / LittleFS layout
- WiFiManager onboarding
- ElegantOTA web updates
- PubSubClient reconnect/publish strategy
- split Web UI and MQTT sections
- JSON config persisted in LittleFS

Device-specific behavior is now focused on:
- analog TDS sampling on A0
- temperature compensation with a DS18B20 probe on D4
- retained MQTT sensor/system state
- Home Assistant discovery for readings and calibration controls

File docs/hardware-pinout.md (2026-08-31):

# TDSTMPSensor Hardware

Board target: Wemos D1 Mini (ESP8266)
TDS Sensor : DFRobot SEN0244
Temperature Sensor : DFRobot DS18B20

## Pin assignments
- `A0`: analog TDS sensor input
- `D2` (`GPIO4`): `DS18B20` one-wire temperature probe
- `D5` (`GPIO14`): emergency factory reset input (jumper to GND at boot)
- `5V`: buck-converter output to the Wemos power input only
- `3V3`: Wemos 3.3 V output to the SEN0244 and DS18B20 power inputs
- `GND`: common ground for the buck converter, Wemos, SEN0244, and DS18B20

## Notes
- The current firmware assumes a Gravity-style analog TDS front-end on `A0`.
- The temperature path is isolated so it can be swapped later if you move away from `DS18B20`.
- On most ESP8266 dev boards, `A0` must stay within the board's supported analog input range.
- The buck converter supplies only the Wemos `5V` input. Do not connect its 5 V output directly to either sensor.
- The SEN0244 and DS18B20 are powered from the Wemos `3V3` and `GND` pins.

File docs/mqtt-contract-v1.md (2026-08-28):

# TDSTMPSensor MQTT Contract v1

Topic namespace base: `tds_tmp_sensor/<node>/`

## Command topics
- `.../cmd`
- `.../ha/cmd`

Examples:

```json
{"cmd":"sample_now"}
{"ha":"sample_now"}
{"ha":"set_tds_calibration","value":1.02}
{"ha":"set_tds_offset","ppm":-12}
{"ha":"set_temp_offset","c":0.4}
{"ha":"set_sample_interval","seconds":10}
{"ha":"set_publish_interval","seconds":60}
{"action":"reboot"}
{"action":"factory_reset"}
```

## State topics
- `.../status`
- `.../health`
- `.../system/state`
- `.../sensors/state`

## Home Assistant discovery
The firmware republishes discovery on reconnect and when Home Assistant publishes `online` to `homeassistant/status`.

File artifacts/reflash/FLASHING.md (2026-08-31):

# Reflash Artifacts

These files were exported from the local build outputs on 2026-08-07 without rebuilding.

## Maintenance Rule

- Update this folder after every new build export.
- Keep only the latest artifact set in this folder.
- When refreshing artifacts, replace older versioned firmware, LittleFS, and ELF files instead of keeping multiple releases here.

## Files

- `TDSTMPSensor-1.0.40-firmware.bin`
- `TDSTMPSensor-1.0.40-littlefs.bin`
- `SHA256SUMS.txt`

## Expected board

- Board: `Wemos D1 Mini`
- MCU: `ESP8266`
- Set `--upload-port` to the serial port assigned to your board.

## Reflash firmware only

```bash
~/.platformio/penv/bin/pio run -t nobuild -t upload --upload-port /dev/cu.usbserial-XXXX
```

That command uses the current `.pio` build output already present in the project and does not rebuild.

## Reflash LittleFS only

> **Warning:** Reflashing LittleFS replaces the filesystem partition. Before running this command, open `Settings > Backup & Restore` at `/settings/backup_restore` and download `config.json`. The LittleFS reflash removes the stored configuration and `sensor_readings.csv`; restore `config.json` through the same page after the update, then reboot the controller. If the configuration is not restored, the device identity and MQTT discovery identifiers can change and Home Assistant will need to be reconfigured.

```bash
~/.platformio/penv/bin/pio run -t nobuild -t uploadfs --upload-port /dev/cu.usbserial-XXXX
```

That also reuses the existing built image already present in `.pio`.

## Reuse exported binaries manually

If you want to flash from the exported files in this folder rather than from `.pio`, use an ESP8266 flashing tool and write:

- firmware image at `0x00000000`
- LittleFS image at `0x00200000`

The flash layout matches `eagle.flash.4m2m.ld` with LittleFS enabled.

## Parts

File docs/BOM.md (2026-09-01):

# TDSTMPSensor Hardware BOM

<p>
  This bill of materials lists the electronics, connectors, assembly hardware, and printable parts used by the TDSTMPSensor project. Quantities are for one sensor assembly unless noted otherwise.
</p>

<h2 id="component-grid">Components</h2>

<table>
  <tr>
    <td valign="top" width="33%">
      <h3>Wemos D1 Mini</h3>
      <p><strong>Quantity:</strong> 1</p>
      <p>ESP8266 controller running the sensor firmware, Web UI, MQTT, and Home Assistant discovery.</p>
      <p align="center">Wemos D1 Mini ESP8266 controller</p>
    </td>
    <td valign="top" width="33%">
      <h3>DFRobot SEN0244</h3>
      <p><strong>Quantity:</strong> 1</p>
      <p>Analog TDS sensor. Specified measurement range: 0-1000 ppm.</p>
      <p align="center">DFRobot SEN0244 analog TDS sensor</p>
    </td>
    <td valign="top" width="33%">
      <h3>DFRobot DS18B20</h3>
      <p><strong>Quantity:</strong> 1</p>
      <p>Waterproof temperature probe used for temperature compensation.</p>
      <p align="center">DFRobot DS18B20 temperature probe</p>
    </td>
  </tr>
  <tr>
    <td valign="top">
      <h3>Buck converter</h3>
      <p><strong>Quantity:</strong> 1</p>
      <p>12-24 V input to regulated 5 V output, 3 A module. The 5 V output feeds the Wemos only; the sensors use the Wemos 3.3 V rail.</p>
      <p align="center">12-24 V to 5 V buck converter</p>
    </td>
    <td valign="top">
      <h3>Lever wire connectors</h3>
      <p><strong>Quantity:</strong> 4</p>
      <p>Three-position electrical lever connectors for serviceable power wiring.</p>
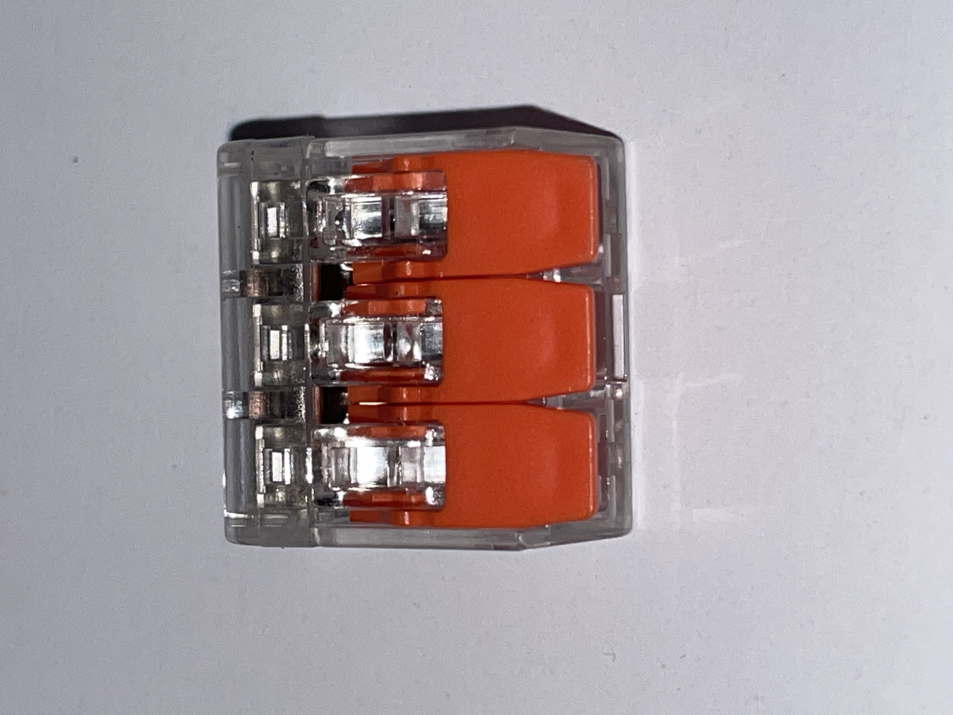
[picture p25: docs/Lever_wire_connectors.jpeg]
Three-position lever wire connector block
      
    </td>
    <td valign="top">
      <h3>JST-XH connector kit</h3>
      <p><strong>Quantity:</strong> 1 kit</p>
      <p>XH2.54 housings and contacts for the sensor and controller harness.</p>
      <p align="center">JST-XH connector kit</p>
    </td>
  </tr>
  <tr>
    <td valign="top">
      <h3>Prewired XH2.54 cables</h3>
      <p><strong>Quantity:</strong> As required</p>
      <p>Prewired and crimped connector cables used to reduce assembly time.</p>
      <p align="center">Prewired JST-XH connector cables</p>
    </td>
    <td valign="top">
      <h3>XH2.54 female contacts</h3>
      <p><strong>Quantity:</strong> As required</p>
      <p>Female pin contacts for custom wires and replacement harnesses.</p>
      <p align="center">XH2.54 female connector contacts</p>
    </td>
    <td valign="top">
      <h3>JST crimping tool</h3>
      <p><strong>Quantity:</strong> 1</p>
      <p>Small connector crimping tool for JST-XH terminals.</p>
      <p align="center">JST connector crimping tool</p>
    </td>
  </tr>
  <tr>
    <td valign="top">
      <h3>12 V power supply</h3>
      <p><strong>Quantity:</strong> 1</p>
      <p>DC supply connected to the buck converter input. Do not connect it directly to the Wemos or sensors.</p>
      <p><em>Reference image not available.</em></p>
    </td>
    <td valign="top">
      <h3>Cable ties</h3>
      <p><strong>Quantity:</strong> As required</p>
      <p>Harness management and strain relief inside the enclosure.</p>
      <p><em>Reference image not available.</em></p>
    </td>
    <td valign="top">
      <h3>Printable enclosure parts</h3>
      <p><strong>Quantity:</strong> 1 set</p>
      <p>Print the enclosure box and the PCB/sensor support plate.</p>
      <p align="center">
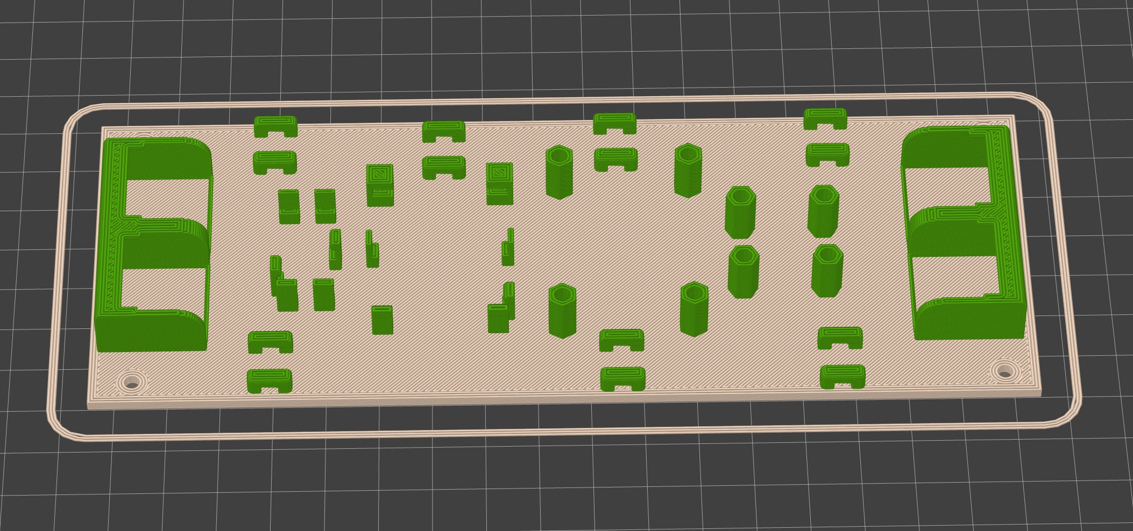
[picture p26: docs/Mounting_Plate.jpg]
3D preview of the printed PCB and sensor mounting plate
        <br>
        <em>Mounting plate preview</em>
      </p>
      <p align="center">
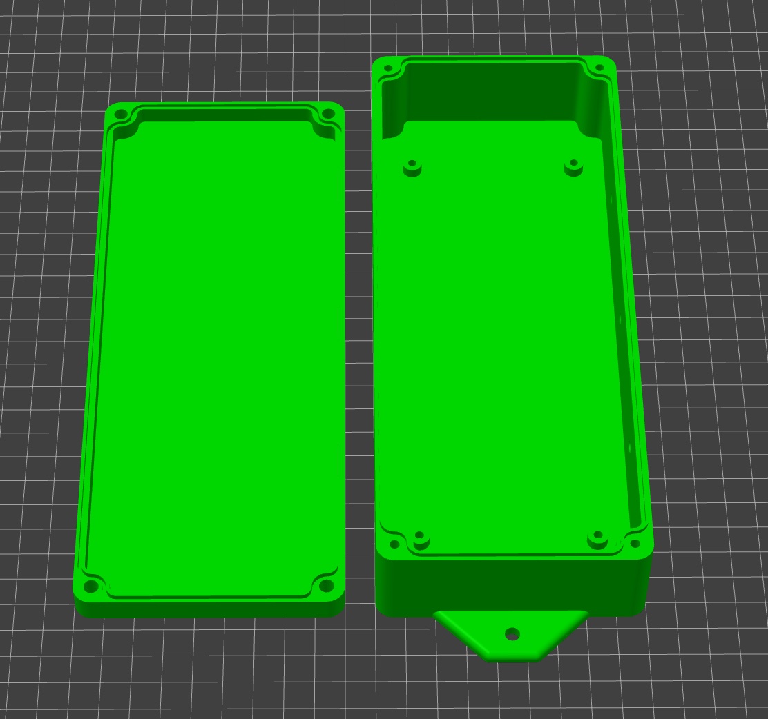
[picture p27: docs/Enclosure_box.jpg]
3D preview of the printed enclosure box
        <br>
        <em>Enclosure box preview</em>
      </p>
      <p><a href="../Enclosure%20and%20mount/Box.3mf">Box.3mf</a><br><a href="../Enclosure%20and%20mount/Sensor%20Plate.3mf">Sensor Plate.3mf</a></p>
    </td>
  </tr>
</table>

<h2 id="assembly-hardware">Assembly hardware</h2>

<table>
  <thead>
    <tr>
      <th>Hardware</th>
      <th>Quantity</th>
      <th>Use</th>
    </tr>
  </thead>
  <tbody>
    <tr>
      <td>M3 x 16 screws</td>
      <td>4</td>
      <td>General enclosure or component assembly</td>
    </tr>
    <tr>
      <td>M3 x 6 screws</td>
      <td>6</td>
      <td>PCB mounting</td>
    </tr>
    <tr>
      <td>M3 x 10 screws</td>
      <td>4</td>
      <td>Support plate mounting</td>
    </tr>
  </tbody>
</table>

<h2 id="component-images">Component images</h2>

<p>
  The component cards above contain the available reference images. The images are also kept as individual files in this folder so they can be reused in other documentation pages.
</p>

<h2 id="printable-parts-and-credits">Printable parts and credits</h2>

<table>
  <thead>
    <tr>
      <th>Part or holder</th>
      <th>Source</th>
    </tr>
  </thead>
  <tbody>
    <tr>
      <td>Wemos D1 Mini board holder</td>
      <td><a href="https://www.printables.com/model/48425-wemos-d1-mini-frame-module-for-enclosures-openscad">Printables model 48425</a></td>
    </tr>
    <tr>
      <td>Capacitor holder</td>
      <td><a href="https://www.thingiverse.com/thing:4089178">Thingiverse model 4089178</a></td>
    </tr>
    <tr>
      <td>Generic lever wire connector holder</td>
      <td><a href="https://www.printables.com/model/170622-generic-lever-wire-connector-holder">Printables model 170622</a></td>
    </tr>
    <tr>
      <td>Cable tie holder</td>
      <td><a href="https://github.com/pfliegster/cable-tie-holders">pfliegster/cable-tie-holders</a></td>
    </tr>
    <tr>
      <td>Standoff</td>
      <td><a href="https://www.thingiverse.com/thing:351092">Thingiverse model 351092</a></td>
    </tr>
    <tr>
      <td>Enclosure box</td>
      <td><a href="https://www.printables.com/model/72839-customizable-parametric-stable-and-waterproof-elec">Printables enclosure model 72839</a></td>
    </tr>
  </tbody>
</table>

<h2 id="power-and-wiring-note">Power and wiring note</h2>

<p>
  The power path is <strong>12 V supply &rarr; buck converter &rarr; Wemos 5V</strong>. The SEN0244 and DS18B20 receive power from the Wemos <code>3V3</code> and <code>GND</code> pins. See the <a href="hardware-pinout.md">hardware pinout</a> and the <a href="../README.md#wiring">Wiring</a> section for the complete connection details.
</p>

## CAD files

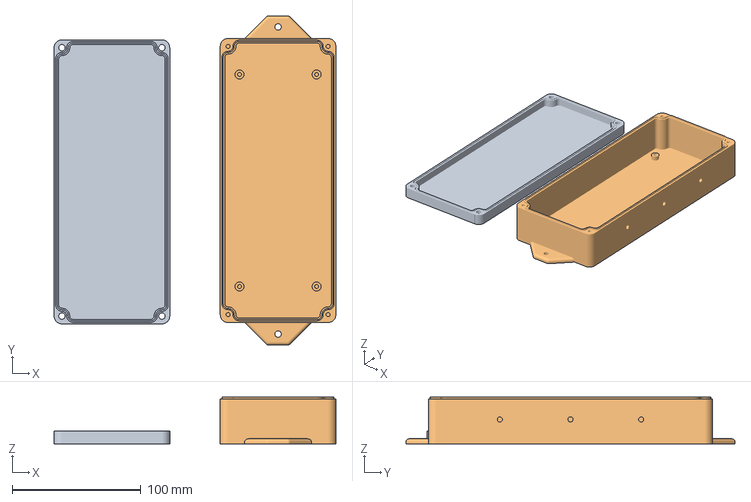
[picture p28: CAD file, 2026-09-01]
Enclosure and mount/Box.3mf
219.3 x 256.0 x 36.4 mm
Boite.stl_1
Merged

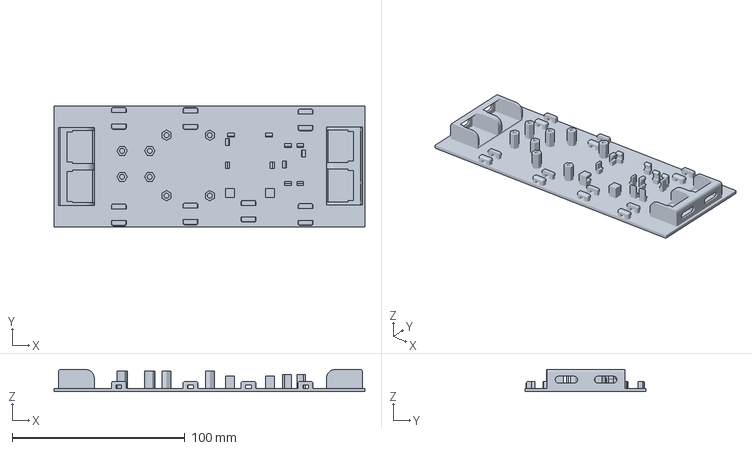
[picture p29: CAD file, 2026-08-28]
Enclosure and mount/Sensor Plate.3mf
180.0 x 70.0 x 13.0 mm

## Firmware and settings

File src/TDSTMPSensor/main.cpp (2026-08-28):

#include <Arduino.h>
#include <ESP8266WiFi.h>
#include <WiFiManager.h>
#include <ESP8266mDNS.h>
#include <ESP8266WebServer.h>
#include <ElegantOTA.h>
#include <PubSubClient.h>
#include <ArduinoJson.h>
#include <LittleFS.h>
#include <OneWire.h>
#include <DallasTemperature.h>
#include <time.h>
#include <stdarg.h>
#include <math.h>
#include "fw_version_auto.h"

#ifndef FW_VERSION
#define FW_VERSION "0.0.0-dev"
#endif

#ifndef FW_BUILD_STAMP
#define FW_BUILD_STAMP "unknown"
#endif

#define DEVICE_NAME_LEN 32
#define MQTT_HOST_LEN 40
#define MQTT_CLIENT_ID_LEN 32
#define MQTT_USER_LEN 24
#define MQTT_PASS_LEN 32
#define OTA_USER_LEN 24
#define OTA_PASS_LEN 24
#define WEB_UI_SESSION_TOKEN_LEN 33
#define IPV4_STR_LEN 16
#define TIMEZONE_LEN 64
#define MQTT_TOPIC_SEGMENT_LEN 32
#define MQTT_TOPIC_BASE_LEN 96
#define MQTT_TOPIC_LEN 128

const char* DEFAULT_DEVICE_NAME_BASE = "tds-tmp-sensor";
const char* DEFAULT_MQTT_CLIENT_ID_BASE = "TDSTMPSensor";
const char* PREFERRED_TEMP_SENSOR_MODEL = "DS18B20";
const char* CONFIG_PATH = "/config.json";
const uint8_t TEMP_SENSOR_PIN = D2;
const uint8_t FACTORY_RESET_PIN = D5;
const unsigned long FACTORY_RESET_HOLD_MS = 3000UL;
const unsigned long MQTT_DANGEROUS_CMD_GUARD_MS = 60000UL;
const unsigned long mqttInterval = 5000UL;
const uint16_t MQTT_KEEPALIVE_SEC = 180;
const unsigned long TIME_SYNC_INTERVAL_MS = 12UL * 60UL * 60UL * 1000UL;
const unsigned long TIME_SYNC_RETRY_MS = 60000UL;
const time_t TIME_VALID_AFTER_EPOCH = 1704067200;
const char* NTP_SERVER_PRIMARY = "pool.ntp.org";
const char* NTP_SERVER_SECONDARY = "time.nist.gov";
const uint8_t TDS_SAMPLE_COUNT = 30;
const unsigned long TDS_ANALOG_SAMPLE_INTERVAL_MS = 40UL;
const float TDS_FALLBACK_TEMP_C = 25.0f;
const char* SENSOR_LOG_CSV_PATH = "/sensor_readings.csv";
const size_t SENSOR_LOG_MAX_BYTES = 102400;
const uint8_t SENSOR_LOG_RECENT_MAX_ENTRIES = 10;
const size_t SENSOR_LOG_LINE_BUF_LEN = 128;

char deviceName[DEVICE_NAME_LEN] = "tds-tmp-sensor";
char mqttBroker[MQTT_HOST_LEN] = "127.0.0.1";
uint16_t mqttPort = 1883;
char mqttClientId[MQTT_CLIENT_ID_LEN] = "TDSTMPSensor";
char mqttUser[MQTT_USER_LEN] = "homeassistant";
char mqttPass[MQTT_PASS_LEN] = "homeassistantpass";
char otaUser[OTA_USER_LEN] = "admin";
char otaPass[OTA_PASS_LEN] = "adminpass";
bool webUiLoginRequired = true;
char webUiSessionToken[WEB_UI_SESSION_TOKEN_LEN] = "";
bool networkUseDhcp = true;
char networkIp[IPV4_STR_LEN] = "";
char networkGateway[IPV4_STR_LEN] = "";
char networkNetmask[IPV4_STR_LEN] = "";
char networkDns[IPV4_STR_LEN] = "";
char timeZoneSpec[TIMEZONE_LEN] = "EST5EDT,M3.2.0/2,M11.1.0/2";
char mqttTopicNode[MQTT_TOPIC_SEGMENT_LEN] = "tds_tmp_sensor";
char MQTT_TOPIC_BASE[MQTT_TOPIC_BASE_LEN] = "tds_tmp_sensor/tds_tmp_sensor";
char MQTT_TOPIC_AVAIL[MQTT_TOPIC_LEN] = "tds_tmp_sensor/tds_tmp_sensor/status";
char MQTT_TOPIC_HEALTH[MQTT_TOPIC_LEN] = "tds_tmp_sensor/tds_tmp_sensor/health";
char MQTT_TOPIC_SYSTEM_STATE[MQTT_TOPIC_LEN] = "tds_tmp_sensor/tds_tmp_sensor/system/state";
char MQTT_TOPIC_SENSOR_STATE[MQTT_TOPIC_LEN] = "tds_tmp_sensor/tds_tmp_sensor/sensors/state";
char MQTT_TOPIC_CONTROL_STATE[MQTT_TOPIC_LEN] = "tds_tmp_sensor/tds_tmp_sensor/controls/state";
char MQTT_TOPIC_CMD[MQTT_TOPIC_LEN] = "tds_tmp_sensor/tds_tmp_sensor/cmd";
char MQTT_TOPIC_HA_CMD[MQTT_TOPIC_LEN] = "tds_tmp_sensor/tds_tmp_sensor/ha/cmd";
char MQTT_TOPIC_CMD_ACK[MQTT_TOPIC_LEN] = "tds_tmp_sensor/tds_tmp_sensor/cmd/ack";
const char* MQTT_TOPIC_HA_STATUS = "homeassistant/status";

struct SensorRuntime
{
    float temperatureC;
    float tdsPpm;
    float voltage;
    float temperatureRawC;
    uint16_t rawAdc;
    bool temperatureValid;
    bool tempBusParasitePower;
    uint8_t tempDeviceCount;
    bool tempAddressValid;
    char tempAddressHex[24];
    unsigned long sampledAtMs;
    time_t sampledAtEpoch;
    uint32_t sampleCount;
};

SensorRuntime sensorState = {0.0f, 0.0f, 0.0f, DEVICE_DISCONNECTED_C, 0, false, false, 0, false, "", 0UL, 0, 0};

float tdsCalibrationFactor = 1.0f;
float tdsOffsetPpm = 0.0f;
float tempOffsetC = 0.0f;
float tdsVref = 3.30f;
float tdsTempCompCutoffV = 2.3396f;
uint16_t sampleIntervalSec = 10;
uint32_t publishIntervalSec = 60;
uint32_t logSampleIntervalMin = 15;
unsigned long lastSampleMs = 0;
unsigned long lastPublishMs = 0;
unsigned long lastLogSampleMs = 0;
unsigned long lastMQTTAttempt = 0;
unsigned long lastTimeSyncMs = 0;
unsigned long bootMs = 0;
uint32_t mqttReconnectCount = 0;
uint32_t minFreeHeap = UINT32_MAX;
bool timeSyncHadValidTime = false;
bool sensorStatePublishPending = false;
bool haDiscoveryPublishPending = false;
unsigned long sensorStatePublishAfterMs = 0;
unsigned long haDiscoveryPublishAfterMs = 0;
int tdsAnalogBuffer[TDS_SAMPLE_COUNT] = {0};
int tdsAnalogBufferTemp[TDS_SAMPLE_COUNT] = {0};
uint8_t tdsAnalogBufferIndex = 0;
bool tdsAnalogBufferPrimed = false;
unsigned long lastTdsAnalogSampleMs = 0;

WiFiManager wm;
ESP8266WebServer server(80);
WiFiClient espClient;
PubSubClient mqttClient(espClient);
OneWire oneWire(TEMP_SENSOR_PIN);
DallasTemperature tempSensors(&oneWire);

void printBootInfo();
void printHealth();
void setupWiFi();
void setupWebServer();
void setupOTA();
void setupMQTT();
void ensureMQTT();
void mqttCallback(char* topic, byte* payload, unsigned int length);
void setupTimeSync();
void processTimeSync();
void requestTimeSync(const char* reason);
bool hasValidSystemTime();
void applyTimeZone();
void applyDefaultIdentityFromMac();
void rebuildMqttTopics();
bool isValidTimeZoneSpec(const String& tzSpec);
void sampleSensors();
void publishSensorState();
void publishSystemState();
void publishControlState();
bool publishHADiscovery();
void processDeferredPublishes();
void requestSensorStatePublish(unsigned long delayMs);
void requestHADiscoveryPublish(unsigned long delayMs);
void publishCmdAck(bool ok, const char* type, const char* detail);
void performFactoryReset(bool wipeFileSystem);
void checkHardwareFactoryReset();
void saveConfig();
void loadConfig();
void appendDebugLog(const char* fmt, ...);
void clearDebugLog();
String normalizeWebUiPath(const String& rawPath);
String buildWebUiSessionCookie();
String generateWebUiSessionToken();
String buildExpectedWebUiSessionToken();
void clearWebUiSession();
bool hasValidWebUiSession();
bool ensureWebUiAuth();
bool sendLittleFSFile(const String& path, bool noCache);
String formatUptimeCompact();
bool canExecuteDangerousMqttCommand();
bool isValidIpv4String(const String& value);
bool parseIpString(const char* text, IPAddress& out);
float parseLocalizedFloatArg(const String& rawValue, float fallbackValue);
long parseLocalizedLongArg(const String& rawValue, long fallbackValue);
void appendWebUiPageStart(String& html, const char* title, const char* heading);
void appendWebUiPageEnd(String& html);
void processTdsAnalogSampling();
int getMedianNum(const int* source, size_t len);
void appendSensorLogCsv();
void processSensorLogging();
uint8_t loadRecentSensorLogLines(char lines[][SENSOR_LOG_LINE_BUF_LEN], uint8_t maxEntries);
void appendHtmlEscaped(String& out, const char* text);

#include "mqtt_section.h"
#include "web_ui_section.h"

static bool isBlankOrDefault(const char* value, const char* def)
{
    if (!value || value[0] == '\0')
        return true;
    return strcmp(value, def) == 0;
}

void applyDefaultIdentityFromMac()
{
    uint32_t chipId = ESP.getChipId();
    char suffix[9];
    snprintf(suffix, sizeof(suffix), "%06X", (unsigned int)(chipId & 0xFFFFFF));

    if (isBlankOrDefault(deviceName, DEFAULT_DEVICE_NAME_BASE))
        snprintf(deviceName, sizeof(deviceName), "%s-%s", DEFAULT_DEVICE_NAME_BASE, suffix);
    if (isBlankOrDefault(mqttClientId, DEFAULT_MQTT_CLIENT_ID_BASE))
        snprintf(mqttClientId, sizeof(mqttClientId), "%s-%s", DEFAULT_MQTT_CLIENT_ID_BASE, suffix);
    if (strcmp(mqttTopicNode, "tds_tmp_sensor") == 0 || mqttTopicNode[0] == '\0')
        snprintf(mqttTopicNode, sizeof(mqttTopicNode), "tds_tmp_%s", suffix);
}

void rebuildMqttTopics()
{
    snprintf(MQTT_TOPIC_BASE, sizeof(MQTT_TOPIC_BASE), "tds_tmp_sensor/%s", mqttTopicNode);
    snprintf(MQTT_TOPIC_AVAIL, sizeof(MQTT_TOPIC_AVAIL), "%s/status", MQTT_TOPIC_BASE);
    snprintf(MQTT_TOPIC_HEALTH, sizeof(MQTT_TOPIC_HEALTH), "%s/health", MQTT_TOPIC_BASE);
    snprintf(MQTT_TOPIC_SYSTEM_STATE, sizeof(MQTT_TOPIC_SYSTEM_STATE), "%s/system/state", MQTT_TOPIC_BASE);
    snprintf(MQTT_TOPIC_SENSOR_STATE, sizeof(MQTT_TOPIC_SENSOR_STATE), "%s/sensors/state", MQTT_TOPIC_BASE);
    snprintf(MQTT_TOPIC_CONTROL_STATE, sizeof(MQTT_TOPIC_CONTROL_STATE), "%s/controls/state", MQTT_TOPIC_BASE);
    snprintf(MQTT_TOPIC_CMD, sizeof(MQTT_TOPIC_CMD), "%s/cmd", MQTT_TOPIC_BASE);
    snprintf(MQTT_TOPIC_HA_CMD, sizeof(MQTT_TOPIC_HA_CMD), "%s/ha/cmd", MQTT_TOPIC_BASE);
    snprintf(MQTT_TOPIC_CMD_ACK, sizeof(MQTT_TOPIC_CMD_ACK), "%s/cmd/ack", MQTT_TOPIC_BASE);
}

void printBootInfo()
{
    Serial.println();
    Serial.println("========================================");
    Serial.println("TDSTMPSensor boot");
    Serial.print("FW version: ");
    Serial.println(FW_VERSION);
    Serial.print("Build stamp: ");
    Serial.println(FW_BUILD_STAMP);
    Serial.print("Device name: ");
    Serial.println(deviceName);
    Serial.print("MQTT base: ");
    Serial.println(MQTT_TOPIC_BASE);
    Serial.println("========================================");
}

void appendDebugLog(const char* fmt, ...)
{
    char buffer[192];
    va_list args;
    va_start(args, fmt);
    vsnprintf(buffer, sizeof(buffer), fmt, args);
    va_end(args);
    Serial.println(buffer);
}

void clearDebugLog()
{
}

uint8_t configSecretKeyByte(size_t index)
{
    static const uint8_t k[] = {0x41, 0x13, 0x5A, 0xD2, 0x27, 0x90, 0x6C, 0x3E};
    return k[index % sizeof(k)];
}

int hexNibbleFromChar(char c)
{
    if (c >= '0' && c <= '9') return c - '0';
    if (c >= 'a' && c <= 'f') return 10 + (c - 'a');
    if (c >= 'A' && c <= 'F') return 10 + (c - 'A');
    return -1;
}

String obfuscateConfigSecret(const char* plain)
{
    if (!plain)
        return "";
    String out;
    const char* hex = "0123456789ABCDEF";
    for (size_t i = 0; plain[i] != '\0'; ++i)
    {
        uint8_t value = ((uint8_t)plain[i]) ^ configSecretKeyByte(i);
        out += hex[(value >> 4) & 0x0F];
        out += hex[value & 0x0F];
    }
    return out;
}

bool deobfuscateConfigSecret(const char* stored, char* out, size_t outLen)
{
    if (!out || outLen == 0)
        return false;
    out[0] = '\0';
    if (!stored || stored[0] == '\0')
        return true;

    size_t len = strlen(stored);
    if ((len % 2) != 0)
        return false;

    size_t plainLen = len / 2;
    if (plainLen >= outLen)
        plainLen = outLen - 1;

    for (size_t i = 0; i < plainLen; ++i)
    {
        int hi = hexNibbleFromChar(stored[i * 2]);
        int lo = hexNibbleFromChar(stored[i * 2 + 1]);
        if (hi < 0 || lo < 0)
            return false;
        out[i] = (char)(((hi << 4) | lo) ^ configSecretKeyByte(i));
    }
    out[plainLen] = '\0';
    return true;
}

void saveConfig()
{
    DynamicJsonDocument doc(3072);
    doc["device_name"] = deviceName;
    doc["mqtt_broker"] = mqttBroker;
    doc["mqtt_port"] = mqttPort;
    doc["mqtt_client_id"] = mqttClientId;
    doc["mqtt_user"] = mqttUser;
    doc["mqtt_pass_obf"] = obfuscateConfigSecret(mqttPass);
    doc["ota_user"] = otaUser;
    doc["ota_pass_obf"] = obfuscateConfigSecret(otaPass);
    doc["web_ui_login_required"] = webUiLoginRequired;
    doc["network_use_dhcp"] = networkUseDhcp;
    doc["network_ip"] = networkIp;
    doc["network_gateway"] = networkGateway;
    doc["network_netmask"] = networkNetmask;
    doc["network_dns"] = networkDns;
    doc["time_zone"] = timeZoneSpec;
    doc["mqtt_topic_node"] = mqttTopicNode;
    doc["tds_calibration_factor"] = tdsCalibrationFactor;
    doc["tds_offset_ppm"] = tdsOffsetPpm;
    doc["temp_offset_c"] = tempOffsetC;
    doc["tds_vref"] = tdsVref;
    doc["tds_temp_comp_cutoff_v"] = tdsTempCompCutoffV;
    doc["sample_interval_sec"] = sampleIntervalSec;
    doc["publish_interval_sec"] = publishIntervalSec;
    doc["log_sample_interval_min"] = logSampleIntervalMin;

    File f = LittleFS.open(CONFIG_PATH, "w");
    if (!f)
    {
        Serial.println("[CFG] Failed to open config for write");
        return;
    }
    serializeJsonPretty(doc, f);
    f.close();
}

void loadConfig()
{
    if (!LittleFS.exists(CONFIG_PATH))
        return;

    File f = LittleFS.open(CONFIG_PATH, "r");
    if (!f)
        return;

    DynamicJsonDocument doc(3072);
    DeserializationError err = deserializeJson(doc, f);
    f.close();
    if (err || !doc.is<JsonObject>())
    {
        Serial.println("[CFG] Invalid config.json");
        return;
    }

    strlcpy(deviceName, doc["device_name"] | deviceName, sizeof(deviceName));
    strlcpy(mqttBroker, doc["mqtt_broker"] | mqttBroker, sizeof(mqttBroker));
    mqttPort = (uint16_t)(doc["mqtt_port"] | mqttPort);
    strlcpy(mqttClientId, doc["mqtt_client_id"] | mqttClientId, sizeof(mqttClientId));
    strlcpy(mqttUser, doc["mqtt_user"] | mqttUser, sizeof(mqttUser));
    strlcpy(otaUser, doc["ota_user"] | otaUser, sizeof(otaUser));
    networkUseDhcp = doc["network_use_dhcp"] | networkUseDhcp;
    strlcpy(networkIp, doc["network_ip"] | networkIp, sizeof(networkIp));
    strlcpy(networkGateway, doc["network_gateway"] | networkGateway, sizeof(networkGateway));
    strlcpy(networkNetmask, doc["network_netmask"] | networkNetmask, sizeof(networkNetmask));
    strlcpy(networkDns, doc["network_dns"] | networkDns, sizeof(networkDns));
    strlcpy(timeZoneSpec, doc["time_zone"] | timeZoneSpec, sizeof(timeZoneSpec));
    strlcpy(mqttTopicNode, doc["mqtt_topic_node"] | mqttTopicNode, sizeof(mqttTopicNode));
    webUiLoginRequired = doc["web_ui_login_required"] | webUiLoginRequired;
    tdsCalibrationFactor = doc["tds_calibration_factor"] | tdsCalibrationFactor;
    tdsOffsetPpm = doc["tds_offset_ppm"] | tdsOffsetPpm;
    tempOffsetC = doc["temp_offset_c"] | tempOffsetC;
    tdsVref = doc["tds_vref"] | tdsVref;
    tdsTempCompCutoffV = doc["tds_temp_comp_cutoff_v"] | tdsTempCompCutoffV;
    sampleIntervalSec = doc["sample_interval_sec"] | sampleIntervalSec;
    publishIntervalSec = doc["publish_interval_sec"] | publishIntervalSec;
    logSampleIntervalMin = doc["log_sample_interval_min"] | logSampleIntervalMin;

    char plain[MQTT_PASS_LEN];
    if (deobfuscateConfigSecret(doc["mqtt_pass_obf"] | "", plain, sizeof(plain)))
        strlcpy(mqttPass, plain, sizeof(mqttPass));
    if (deobfuscateConfigSecret(doc["ota_pass_obf"] | "", plain, sizeof(plain)))
        strlcpy(otaPass, plain, sizeof(otaPass));

    if (sampleIntervalSec < 1) sampleIntervalSec = 1;
    if (sampleIntervalSec > 3600) sampleIntervalSec = 3600;
    if (publishIntervalSec < 5) publishIntervalSec = 5;
    if (publishIntervalSec > 86400) publishIntervalSec = 86400;
    if (logSampleIntervalMin > 10080) logSampleIntervalMin = 10080;
    if (tdsVref < 1.0f) tdsVref = 1.0f;
    if (tdsVref > 5.0f) tdsVref = 5.0f;
    if (tdsTempCompCutoffV < 0.0f) tdsTempCompCutoffV = 0.0f;
    if (tdsTempCompCutoffV > tdsVref) tdsTempCompCutoffV = tdsVref;
}

bool parseIpString(const char* text, IPAddress& out)
{
    if (!text || text[0] == '\0')
        return false;
    return out.fromString(text);
}

bool isValidIpv4String(const String& value)
{
    IPAddress ip;
    return value.length() > 0 && ip.fromString(value);
}

void sampleSensors()
{
    if (!tdsAnalogBufferPrimed)
    {
        for (uint8_t i = 0; i < TDS_SAMPLE_COUNT; ++i)
        {
            tdsAnalogBuffer[i] = analogRead(A0);
            delay(5);
        }
        tdsAnalogBufferPrimed = true;
    }

    sensorState.rawAdc = (uint16_t)getMedianNum(tdsAnalogBuffer, TDS_SAMPLE_COUNT);
    sensorState.voltage = ((float)sensorState.rawAdc * tdsVref) / 1024.0f;

    sensorState.tempDeviceCount = tempSensors.getDeviceCount();
    sensorState.tempBusParasitePower = tempSensors.isParasitePowerMode();
    DeviceAddress addr;
    sensorState.tempAddressValid = (sensorState.tempDeviceCount > 0) && tempSensors.getAddress(addr, 0);
    if (sensorState.tempAddressValid)
    {
        snprintf(
            sensorState.tempAddressHex,
            sizeof(sensorState.tempAddressHex),
            "%02X%02X%02X%02X%02X%02X%02X%02X",
            addr[0], addr[1], addr[2], addr[3], addr[4], addr[5], addr[6], addr[7]);
    }
    else
    {
        sensorState.tempAddressHex[0] = '\0';
    }

    tempSensors.requestTemperatures();
    float rawTemp = tempSensors.getTempCByIndex(0);
    sensorState.temperatureRawC = rawTemp;
    sensorState.temperatureValid = (rawTemp > -100.0f && rawTemp < 125.0f);
    float compensationTemperatureC = TDS_FALLBACK_TEMP_C;
    if (sensorState.temperatureValid)
    {
        sensorState.temperatureC = rawTemp + tempOffsetC;
        compensationTemperatureC = sensorState.temperatureC;
    }
    else
    {
        sensorState.temperatureC = TDS_FALLBACK_TEMP_C + tempOffsetC;
    }

    float compensationCoefficient = 1.0f + 0.02f * (compensationTemperatureC - 25.0f);
    if (fabsf(compensationCoefficient) < 0.01f)
        compensationCoefficient = 1.0f;
    float compensatedVoltage = sensorState.voltage;
    if (sensorState.voltage < tdsTempCompCutoffV)
        compensatedVoltage = sensorState.voltage / compensationCoefficient;
    float tds = (133.42f * compensatedVoltage * compensatedVoltage * compensatedVoltage
        - 255.86f * compensatedVoltage * compensatedVoltage
        + 857.39f * compensatedVoltage) * 0.5f;
    tds = (tds * tdsCalibrationFactor) + tdsOffsetPpm;
    if (tds < 0.0f)
        tds = 0.0f;

    sensorState.tdsPpm = tds;
    sensorState.sampledAtMs = millis();
    sensorState.sampledAtEpoch = time(nullptr);
    sensorState.sampleCount++;

    requestSensorStatePublish(0);
}

void processTdsAnalogSampling()
{
    unsigned long now = millis();
    if (now - lastTdsAnalogSampleMs < TDS_ANALOG_SAMPLE_INTERVAL_MS)
        return;

    lastTdsAnalogSampleMs = now;
    tdsAnalogBuffer[tdsAnalogBufferIndex] = analogRead(A0);
    tdsAnalogBufferIndex++;
    if (tdsAnalogBufferIndex >= TDS_SAMPLE_COUNT)
    {
        tdsAnalogBufferIndex = 0;
        tdsAnalogBufferPrimed = true;
    }
}

int getMedianNum(const int* source, size_t len)
{
    if (!source || len == 0)
        return 0;

    if (len > TDS_SAMPLE_COUNT)
        len = TDS_SAMPLE_COUNT;

    for (size_t i = 0; i < len; ++i)
        tdsAnalogBufferTemp[i] = source[i];

    for (size_t j = 0; j < len; ++j)
    {
        for (size_t i = 0; i + 1 < len - j; ++i)
        {
            if (tdsAnalogBufferTemp[i] > tdsAnalogBufferTemp[i + 1])
            {
                int tmp = tdsAnalogBufferTemp[i];
                tdsAnalogBufferTemp[i] = tdsAnalogBufferTemp[i + 1];
                tdsAnalogBufferTemp[i + 1] = tmp;
            }
        }
    }

    if ((len & 1U) != 0U)
        return tdsAnalogBufferTemp[(len - 1U) / 2U];

    return (tdsAnalogBufferTemp[len / 2U] + tdsAnalogBufferTemp[(len / 2U) - 1U]) / 2;
}

void appendSensorLogCsv()
{
    if (sensorState.sampleCount == 0)
        return;

    bool shouldWriteHeader = false;
    if (LittleFS.exists(SENSOR_LOG_CSV_PATH))
    {
        File fCheck = LittleFS.open(SENSOR_LOG_CSV_PATH, "r");
        if (fCheck)
        {
            size_t currentSize = fCheck.size();
            fCheck.close();
            if (currentSize >= SENSOR_LOG_MAX_BYTES)
                LittleFS.remove(SENSOR_LOG_CSV_PATH);
            else if (currentSize == 0)
                shouldWriteHeader = true;
        }
    }
    else
    {
        shouldWriteHeader = true;
    }

    if (!LittleFS.exists(SENSOR_LOG_CSV_PATH))
        shouldWriteHeader = true;

    File f = LittleFS.open(SENSOR_LOG_CSV_PATH, "a");
    if (!f)
        return;

    if (shouldWriteHeader)
    {
        static const char* kSensorLogHeader = "Date, Temperature C, TDS PPM, Raw ADC, Voltage V\n";
        f.write((const uint8_t*)kSensorLogHeader, strlen(kSensorLogHeader));
    }

    char timestamp[24];
    if (hasValidSystemTime())
    {
        time_t nowTs = time(nullptr);
        struct tm localTm;
        localtime_r(&nowTs, &localTm);
        strftime(timestamp, sizeof(timestamp), "%Y-%m-%d %H:%M:%S", &localTm);
    }
    else
    {
        unsigned long totalSec = millis() / 1000UL;
        unsigned long hh = (totalSec / 3600UL) % 24UL;
        unsigned long mm = (totalSec / 60UL) % 60UL;
        unsigned long ss = totalSec % 60UL;
        snprintf(timestamp, sizeof(timestamp), "0000-00-00 %02lu:%02lu:%02lu", hh, mm, ss);
    }

    char line[160];
    int n = snprintf(
        line,
        sizeof(line),
        "%s,%.2f,%.2f,%u,%.4f\n",
        timestamp,
        sensorState.temperatureValid ? sensorState.temperatureC : sensorState.temperatureRawC,
        sensorState.tdsPpm,
        (unsigned int)sensorState.rawAdc,
        sensorState.voltage);
    if (n > 0)
        f.write((const uint8_t*)line, (size_t)n);
    f.close();
}
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
void loop()
{
    server.handleClient();
    if (WiFi.status() == WL_CONNECTED)
        MDNS.update();

    processTdsAnalogSampling();
    ensureMQTT();
    mqttClient.loop();
    processTimeSync();
    processDeferredPublishes();
    processSensorLogging();

    unsigned long now = millis();
    if (isIntervalElapsed(now, &lastSampleMs, (unsigned long)sampleIntervalSec * 1000UL))
        sampleSensors();
    if (isIntervalElapsed(now, &lastPublishMs, (unsigned long)publishIntervalSec * 1000UL))
    {
        requestSensorStatePublish(0);
        printHealth();
    }
}

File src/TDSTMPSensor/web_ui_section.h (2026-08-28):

static File backupRestoreUploadFile;
static bool backupRestoreUploadFailed = false;
static char backupRestoreUploadTmpPath[32] = {0};

static void backupRestoreResetUploadState()
{
    if (backupRestoreUploadFile)
        backupRestoreUploadFile.close();
    backupRestoreUploadFailed = false;
    backupRestoreUploadTmpPath[0] = '\0';
}

static void backupRestoreStartUpload(const char* tmpPath)
{
    backupRestoreResetUploadState();
    strlcpy(backupRestoreUploadTmpPath, tmpPath, sizeof(backupRestoreUploadTmpPath));
    if (LittleFS.exists(backupRestoreUploadTmpPath))
        LittleFS.remove(backupRestoreUploadTmpPath);
    backupRestoreUploadFile = LittleFS.open(backupRestoreUploadTmpPath, "w");
    if (!backupRestoreUploadFile)
        backupRestoreUploadFailed = true;
}

static void backupRestoreWriteUploadChunk(const uint8_t* data, size_t len)
{
    if (backupRestoreUploadFailed || !backupRestoreUploadFile)
        return;
    if (backupRestoreUploadFile.write(data, len) != len)
        backupRestoreUploadFailed = true;
}

static bool backupRestoreFinishUpload(size_t totalSize)
{
    if (backupRestoreUploadFile)
        backupRestoreUploadFile.close();
    if (backupRestoreUploadFailed || totalSize == 0)
        return false;
    return LittleFS.exists(backupRestoreUploadTmpPath);
}

static bool backupRestorePromoteUploadedFile(const char* tmpPath, const char* finalPath)
{
    if (!LittleFS.exists(tmpPath))
        return false;
    if (LittleFS.exists(finalPath))
        LittleFS.remove(finalPath);
    return LittleFS.rename(tmpPath, finalPath);
}

static bool backupRestoreValidateConfigJson(const char* path)
{
    if (!LittleFS.exists(path))
        return false;
    File f = LittleFS.open(path, "r");
    if (!f)
        return false;
    DynamicJsonDocument doc(3072);
    DeserializationError err = deserializeJson(doc, f);
    f.close();
    return !err && doc.is<JsonObject>();
}

void setupWebServer()
{
    const char* headerKeys[] = {"Cookie"};
    server.collectHeaders(headerKeys, sizeof(headerKeys) / sizeof(headerKeys[0]));

#define REQUIRE_WEB_UI_AUTH() do { if (!ensureWebUiAuth()) return; } while (0)

    server.on("/login", HTTP_GET, []()
    {
        if (!webUiLoginRequired)
        {
            server.sendHeader("Location", "/", true);
            server.send(303, "text/plain", "");
            return;
        }

        if (hasValidWebUiSession())
        {
            String next = normalizeWebUiPath(server.arg("next"));
            server.sendHeader("Location", next, true);
            server.send(303, "text/plain", "");
            return;
        }

        String next = normalizeWebUiPath(server.arg("next"));
        bool invalidCreds = (server.hasArg("err") && server.arg("err") == "1");

        String html;
        html.reserve(2800);
        appendWebUiPageStart(html, "TDSTMPSensor - Login", "Sign in");
        html += "<p>Use your OTA credentials to access the Web UI.</p>";
        if (invalidCreds)
            html += "<p><b>Invalid username or password.</b></p>";
        html += "<fieldset class='r'><form method='POST' action='/login'>";
        html += "<input type='hidden' name='next' value='";
        html += next;
        html += "'>";
        html += "Username:<br><input id='username' name='username' type='text' autocomplete='username' autocapitalize='none' autocorrect='off' spellcheck='false'><br><br>";
        html += "Password:<br><input id='password' name='password' type='password' autocomplete='current-password'><br><br>";
        html += "<button type='submit'>Sign in</button></form></fieldset>";
        appendWebUiPageEnd(html);
        server.sendHeader("Cache-Control", "no-store, no-cache, must-revalidate, max-age=0");
        server.sendHeader("Pragma", "no-cache");
        server.sendHeader("Expires", "0");
        server.send(200, "text/html", html);
    });

    server.on("/login", HTTP_POST, []()
    {
        String next = normalizeWebUiPath(server.arg("next"));
        if (server.arg("username") == String(otaUser) && server.arg("password") == String(otaPass))
        {
            String token = generateWebUiSessionToken();
            strlcpy(webUiSessionToken, token.c_str(), sizeof(webUiSessionToken));
            server.sendHeader("Set-Cookie", buildWebUiSessionCookie());
            server.sendHeader("Location", next, true);
            server.send(303, "text/plain", "");
            return;
        }

        clearWebUiSession();
        server.sendHeader("Set-Cookie", "TDSSSESSID=; Path=/; Max-Age=0; HttpOnly; SameSite=Lax");
        server.sendHeader("Location", "/login?err=1&next=" + next, true);
        server.send(303, "text/plain", "");
    });

    server.on("/logout", HTTP_GET, []()
    {
        clearWebUiSession();
        server.sendHeader("Set-Cookie", "TDSSSESSID=; Path=/; Max-Age=0; HttpOnly; SameSite=Lax");
        server.sendHeader("Location", "/login", true);
        server.send(303, "text/plain", "");
    });

    server.on("/ui/app.css", HTTP_GET, []()
    {
        if (!sendLittleFSFile("/web/app.css", true))
            server.send(404, "text/plain", "Missing app.css");
    });

    server.on("/", HTTP_GET, []()
    {
        REQUIRE_WEB_UI_AUTH();
        if (!sendLittleFSFile("/web/index.html", true))
            server.send(404, "text/plain", "Missing index.html");
    });

    server.on("/measurements", HTTP_GET, []()
    {
        if (!sendLittleFSFile("/web/measurements.html", true))
            server.send(404, "text/plain", "Missing measurements.html");
    });

    server.on("/mqtt_send", HTTP_GET, []()
    {
        REQUIRE_WEB_UI_AUTH();
        if (!sendLittleFSFile("/web/mqtt-send.html", true))
            server.send(404, "text/plain", "Missing mqtt-send.html");
    });

    server.on("/mqtt_send", HTTP_POST, []()
    {
        REQUIRE_WEB_UI_AUTH();
        String topic = server.arg("topic");
        String payload = server.arg("payload");
        if (topic.length() == 0 || payload.length() == 0 || !mqttClient.connected())
        {
            server.sendHeader("Location", "/mqtt_send?sent=0", true);
            server.send(303, "text/plain", "");
            return;
        }
        bool ok = mqttClient.publish(topic.c_str(), payload.c_str(), false);
        server.sendHeader("Location", ok ? "/mqtt_send?sent=1" : "/mqtt_send?sent=0", true);
        server.send(303, "text/plain", "");
    });

    server.on("/settings", HTTP_GET, []()
    {
        REQUIRE_WEB_UI_AUTH();
        if (!sendLittleFSFile("/web/settings.html", true))
            server.send(404, "text/plain", "Missing settings.html");
    });

    server.on("/settings/network", HTTP_GET, []()
    {
        REQUIRE_WEB_UI_AUTH();
        sendLittleFSFile("/web/settings-network.html", true);
    });

    server.on("/settings/mqtt", HTTP_GET, []()
    {
        REQUIRE_WEB_UI_AUTH();
        sendLittleFSFile("/web/settings-mqtt.html", true);
    });
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

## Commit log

2026-08-28 Add project documentation and enclosure files
    [Box.3mf, Sensor Plate.3mf]
2026-08-31 Add BOM and component sections to README
2026-08-31 Document soldering and connector assembly
2026-08-31 Document buck converter 5V jumper
2026-08-31 Document default device naming
2026-08-31 Correct sensor power wiring documentation
2026-09-01 Add technical wiring drawing
2026-09-01 Format BOM as component grid
2026-09-01 Add BOM component reference images
2026-09-01 Box update
    [Box.3mf]
